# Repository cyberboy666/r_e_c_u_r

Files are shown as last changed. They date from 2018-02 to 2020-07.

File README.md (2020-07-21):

# r_e_c_u_r

 an open diy video sampler
 
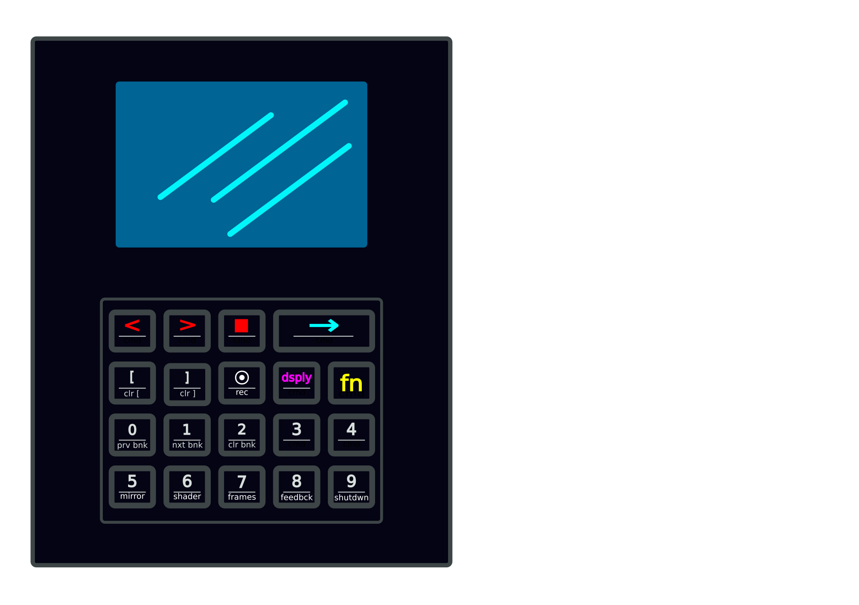
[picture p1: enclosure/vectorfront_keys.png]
vectorfront
 
 
__r_e_c_u_r__ is an embedded python/openframeworks application on _raspberry pi3_ that uses `input` from the _keypad_ to control  `video` while displaying a simple text ui on a _rpi lcd screen_ 

## in-depth video demo

[video-walkthrough](http://www.youtube.com/watch?v=FKKDr7pLpp0)

## features

- seamlessly loop video through rpi's HDMI or composite out
- intuitively _browse_ video files from external and internal disk and map them into __r_e_c_u_r__
- load and trigger video samples from numbered slots in the _sampler_ bank
- dynamically set and clear the start/end points of each sample as it plays
- control and sequence all inputs and more with midi-usb
- many sampler modes for varied playback including: repeat, one-shot, gated, random, fixed-length, random-start and more 
- exhaustive and extendable _settings_ menu  to suit your use

## extensions

as of _V2.0_ the __r_e_c_u_r__ platform has been extended in a number of directions to complement live performance and  _\_recur\__ , the original video playing engine:

- _\_captur\__ : input live video via CSI or USB , for live sampling and processing
- _\_conjur\__ : glsl shader engine, map and trigger shader files and control parameters in real time; generate video or process and mix existing sources
- _\_detour\__ : in-memory frame sampling (up to 500 frames), video scrubbing, playback speed and direction control, finger drumming
- toggling internal feedback + strobe effect 

_NOTE: most of the new V2.0 features are optimised for sd composite video output. Some of these extensions will work over HDMI but they are not fully supported - especially the live video input struggles_

### extension video walkthroughs

- [conjur_walkthrough](https://www.youtube.com/watch?v=ah2HY1fuv8w)
- [captur_walkthrough](https://www.youtube.com/watch?v=e7m_YHEFahs)
- [detour_walkthrough](https://www.youtube.com/watch?v=e9vrzn7c9R8)

## main objectives:

- *Affordable* : reducing the entry cost to performing with video
- *Extendable* : laying the foundations (of a user interface and code style) that can be easily iterated on by the community
- *Simple* : easy to operate (abstracted completely from ‘driving’ a raspi ) , easy to build (no technical computer install-y or circuit-y knowledge required to diy) , easy to develop (human readable code, inviting amateur/first time coders to contribute)

## documentation:

- [operating] - how to use r_e_c_u_r
- [building] - how to diy r_e_c_u_r
- [developing] - how to contribute to r_e_c_u_r

many other things documented on the [wiki]

## status

The nature of this project is to be open-ended and community driven. my r_e_c_u_r already solves the problems i initially built it for. what happens next depends on how it is used and received by you. if you like the idea please let me know / get involved !

## contact, donation and thanks

langolierz@gmail.com

you can find me (and others) at https://scanlines.xyz , an online diy av community space. theres a r_e_c_u_r channel in the chatroom: https://chat.scanlines.xyz/channel/r_e_c_u_r
there is also a facebook user group : https://www.facebook.com/groups/114465402691215/

all feedback is appreciated. if you want to donate to this project you can do so with the above email via paypal : everything i receive will go into improving __r_e_c_u_r__. cheers to Leo Browning for the 3d modelling and vector art and to Ben Caldwell for heaps of help with the code!

[vectorfront]: ./enclosure/vectorfront_keys.png
[video-thumbnail]: https://github.com/langolierz/r_e_c_u_r/wiki/images/video-thumbnail.jpg
[conjur_thumbnail]: https://github.com/langolierz/r_e_c_u_r/wiki/images/conjur_video_thumbnail.jpg
[captur_thumbnail]: https://github.com/langolierz/r_e_c_u_r/wiki/images/captur_video_thumbnail.jpg
[detour_thumbnail]: https://github.com/langolierz/r_e_c_u_r/wiki/images/detour_video_thumbnail.jpg
[operating]: https://github.com/langolierz/r_e_c_u_r/wiki/operate_docs
[building]: https://github.com/langolierz/r_e_c_u_r/wiki/build_docs
[developing]: https://github.com/langolierz/r_e_c_u_r/wiki/develop_docs
[wiki]: https://github.com/langolierz/r_e_c_u_r/wiki

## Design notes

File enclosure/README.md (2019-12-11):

gonna explain a little about the enclosure options here :

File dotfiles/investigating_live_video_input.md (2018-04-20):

# video input

### background

a common feature of audio samplers is the ability to 'live sample' ie have a line in to the device and use this to record a sample directly onto it - usally to be played back again imedantly as part of a performance.

from what i can tell some hardware video samplers also offer this feature. it would be interesting to explore the possiblity of this with recur. some ways to record video into recur include:

- a usb dongle / external capture card
- using a pi camera for live video or rescanning off a screen
- piCapture : a custom video card built for pi to use the pi cam protical

the first option seems fiddly and difficult / a compromise. i might be interested in trying to capture with a Blackmagic Intensity Shuttle if i get one some day...

options 2 and 3 both seem plausable, and hopefully will be interchangable once things are working (piCapture claims to act exactly like a piCam so should painless). also this allows both a cheap/hacky solution (rescanning through $2 camera) or a more professional option ($130 addation) and i can start experimenting now with a cheep cam before investing in the expensive piCapture.

i know piCam and piCapture recommend using python and there is libraries for this

### things to find out

i want to know how plausable it would be to add live sampling to my current recur stack (gpio lcd screen, omxplayer video backend).

some things i want know are:

- how to set up the piCam on raspberry pi
- how to record the input from the piCam onto the pi
- will these files play back in omx/recur
- can you preview the stream on the hdmi/composite output ?
- can you preview the stream on the lcd display ? 
- can this preview be adjusted / resized etc ?
- can you adjust params of camera ? in real time ? framerate , brightness , contrast , zoom etc ? 
- how does rescanning look ?
- how could i control piCaptures additional params ?
- is there any reason to think piCapture wouldnt be interchangable with a working piCam feature ?

### research

[cheep cameras] for raspi can be bought from china with 5 mega pixals / recording 1080p video for around $5usd. i have borrowed a camera ~~which i think is a night-vision version~~ to experiment with , although should order one of these myself.

i started by reading the [picamera] python package docs. this seemed to have lots of options regarding recording video , including starting and stopping both previews and video recordings , the ability to set the resolution , framerate , shutter speed of the camera , switching preview to full screen or setting the size and position of it. 

also a bunch of parameters that might be of interest including brightness , colour effect , contrast , flips and rotations , preview alpha , saturation , sharpness. these apear to be controllable in real time while previewing or recording.

it seems like the output from the camera is raw (without frame per second meta data) h264 and to play the video back at correct speed will need a program to wrap it in an mp4 container :
```
$ sudo apt-get install gpac
...
$ MP4Box -add input.h264 output.mp4
```

the [faq] also addresses the 'can i preview to the lcd screen' question : looks like no - atleast not without copying the exact framebuffer , similar to my experiments displaying omx on the lcd screen. (this still might be possible in the world of openCv but off the table for now! - or maybe not even then - this [adafruit] tutorial talks about the limitations of displaying on a tft screen - "accelerated software will never appear on the PiTFT (it is unaccelerated framebuffer only)" ) 

### an unrelated aside : 

the [adafruit tft display] mentioned above also uses the gpios to connect to the pi - in particular it uses 5 spi pins and two standard pin outs. by cross refferencing the [raspi gpio] docs it does not use either of the rx serial pin , which would be needed if i were to receive midi directly (rather than through usb), it also leaves plenty of pins for receiving cv from a [mcp3008] through software spi for example. it is likely that my gpio lcd screen comunicates with the pi in a similar way and that i could figure out a way to connect these extentions if desired.

### research continued : piCapture

[picapture] is a video capture card designed for the raspberry pi to emulate the piCamera and take advantange of the pi's hardware accelaration. it comes as a 'hat' that also uses ic2 (or serial)
to comunicate. there is a python package to access these addational options. 

these come in two types :

- standard def - composite and s-video in , $139usd
- hi def - hdmi and component in $159usd

im not sure which one i would like to try, but they sound cool ! would need to check the pins dont clash with the display but i think these should work together nicely !

### getting started with piCamera

following the picamera docs , i will/have :

- plugged in the camera
- turned on camera in the config
- tried take an image
- installed package with `sudo apt-get install python3-picamera`
- run `sudo apt-get update` and  `sudo apt-get upgrade` (for firmware)
- trying some simple python commands with camera
- write some experimental recur code

first hitch : i enabled the camera in the raspi-config , but it seems like the switching screens driver overrides this , ~~so will have to update this too !~~ fixed this by adding a line to the config.txt

besides that the preview / different parameters and effects work as expected. next step is to try recording something , converting it to mp4 and playing back on omxplayer.

i have installed `sudo apt-get install gpac` and am using `subprocess.Popen` to run the `MP4Box` command from inside python. this way i can poll back into it and map the video only when its finished converting to stop blocking in the meantime. i also updated the display to show when the camera is previewing and recording. this all worked smoother than i expected.

i also made a (suprizingly small) change to the browser to show the pi's videos folder next to the external devices. this will be useful for using the recordings saved and for copying files onto recurs disk. (the copying feature has been depriotised since it can be done manually with mouse/keyboard and could be risky / might want a confermation window ...)

another thing still to think about is how to protect from overfilling the sd card / external storage. 
- i have done this by checking before starting to record and every 10 seconds during recording if the disk space is under 10mb in which case it warns and stops the recording.

also displaying info when camera is not attached and catching other types of errors... 
- this will be handled by  bool enabling the capture. if it can not detect the camera it will not allow this to be enabled.

[picamera]: http://picamera.readthedocs.io/en/release-1.0/api.html
[faq]: https://picamera.readthedocs.io/en/release-1.13/faq.html
[adafruit]: https://learn.adafruit.com/adafruit-pitft-3-dot-5-touch-screen-for-raspberry-pi/easy-install-2
[adafruit tft display]: https://www.adafruit.com/product/2441
[raspi gpio]: https://www.raspberrypi.org/documentation/usage/gpio/
[mcp3008]: https://learn.adafruit.com/raspberry-pi-analog-to-digital-converters/mcp3008
[cheep cameras]: https://www.aliexpress.com/item/5MP-Camera-Module-Flex-Cable-Webcam-Video-1080-720p-For-Raspberry-Pi-2-3-Model-B/32860830711.html
[picapture]: https://lintestsystems.com/products/picapture-sd1

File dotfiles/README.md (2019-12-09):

# documenting the exact steps to creating the r_e_c_u_r raspbian image

## initial set up ; flashing fresh sd, keyboard , wifi , updates etcs

- downloaded the latest (~~2017-11-29~~ ~~2018-04-18~~ [2019-07-10]) raspbian-raspbian-lite image from offical site.

- flashed it to my sd using etcher

- set up auto console login and changed keyboard layout using `sudo raspi-config`

- following the beginning of [this](https://gist.github.com/kmpm/8e535a12a45a32f6d36cf26c7c6cef51) guide,
set up wifi and run all updates: 

`sudo nano /etc/wpa_supplicant/wpa_supplicant.conf` Add the bottom of the file
```
network={
  ssid="YOUR_SSID"
  psk="YOUR_PASSWORD"
}
```

then `sudo apt update` and `sudo apt upgrade` , sudo reboot

- i trieds to get this working without needing pixel installed (using openbox and a few other bits but the drivers for my screens didnt work like this - decided its not worth shaving that yak rn. will proceed with a stripped pixel as described above:
 
## download/install pixel + all dependencies for r_e_c_u_r : 
 ```
 sudo apt-get install -y raspberrypi-ui-mods git python3-tk omxplayer libdbus-glib-1-dev python3-pip unclutter python3-picamera gpac 
 
 pip3 install dbus-python omxplayer-wrapper  mido python-rtmidi
 ```

- now can set up auto desktop login using `sudo raspi-config`

## download the code in this repo:

- pull down recur code into home dir ~ : `git clone https://github.com/langolierz/r_e_c_u_r.git`

## quiet x and run my launcher script on boot:

- used ~~sudo nano ~/.config/lxsession/LXDE-pi/autostart~~ `sudo nano/etc/xdg/lxsession/LXDE-pi/autostart` to add these lines : 
```
@unclutter -display :0 -idle 0 -root -noevents
@xset s off
@xset s noblank
@xset -dpms
@bash /home/pi/r_e_c_u_r/dotfiles/launcher.sh
```

and remove the line `@point-rpi` 

these are suppose to stop screensaver / hide cursor / remove on screen power warnings etc

- i then went into pi item -> Preferences and set a black background , small task bar , no screensaver  and went into the file explorer -> Edit -> Preferences -> Volume Managment -> unchecked 'show available options for removable media ...' and made taskbar auto hide...

- created internal storage folder in ~/Videos 

- set a custom splash screen by replacing splash.png an image at:
`sudo cp ~/r_e_c_u_r/documentation/splash.png /usr/share/plymouth/themes/pix/splash.png`
 
## for piCaptureSd1

need to install : `sudo apt-get install python3-smbus` and `sudo pip3 install pivideo`

## lcd display drivers

these are the drivers for the waveshare displays that work on the cheep lcd i ordered online ( [LCD-show-170703] ).~~

`git clone https://github.com/waveshare/LCD-show`

my screen only needs the LCD35-show-180 and LCD-hdmi scripts. after running both of these scripts the drivers can be deleted since the recur code then handles the switching. (or keep em if you wanna flip the screen or try calibrating the touch screen)

## installing raspi2fb

i decided to use AndrewFromMelbourne's [raspi2fb] to get a approx of output on the lcd screen. following their readme i installed :

`sudo apt-get install cmake libbsd-dev`

 pulled down the code from home dir  `git clone https://github.com/AndrewFromMelbourne/raspi2fb.git` 
 
 moved into the folder then ran the following commands : 
 ```
 mkdir build
cd build
cmake ..
make
sudo make install
sudo cp ../raspi2fb@.service /etc/systemd/system/
sudo systemctl daemon-reload
sudo systemctl enable raspi2fb@1.service
```
a line to Popen inside the python code toggles this on and off from here.

## lines added to config.txt

the fastest way is to copy the config.txt i included in the repo:

`sudo cp ~/r_e_c_u_r/dotfiles/config.txt /boot/config.txt`

be careful though - messing with the config.txt is the easiest way to brick the image from my experience ... 

or do these :

- commenting out hdmi_force to allow composite output: `#hdmi_force_hotplug=1`

- add these lines to the config:
```
## gives more memory to the gpu for playing 1080 videos (might need to adjust this when using older pis with less memory)
gpu_mem_256=120
gpu_mem_512=200
gpu_mem_1024=448
gpu_mem=600
## enables the raspi camera
start_x=1
## fixes bug with playback freezing
audio_pwm_mode=0

## persisting composite settings
sdtv_mode=00
sdtv_aspect=1

## switch for enabling lcd screen (the next line is being used even if its commented out)
##no_waveshare_overlay
```

## changes to the cmdline.txt

add to end of cmdline.txt `sudo nano /boot/cmdline.txt` : 
`quiet splash logo.nologo plymouth.ignore-serial-consoles` for quiet boot with splash screen 

## installing openframeworks and setting up conjur app

`wget "https://openframeworks.cc/versions/v0.10.1/of_v0.10.1_linuxarmv6l_release.tar.gz"`

- `mkdir openFrameworks` and `tar vxfz of_v0.10.1_linuxarmv6l_release.tar.gz -C openFrameworks --strip-components 1`
- `cd openFrameworks/scripts/linux/debian/` &  `sudo ./install_dependencies.sh`
- `make Release -C ~/openFrameworks/libs/openFrameworksCompiled/project`
- `cd ~/openFrameworks/apps/myApps/` and `git clone https://github.com/langolierz/c_o_n_j_u_r`
- `cd ~/openFrameworks/addons/` and `git clone https://github.com/langolierz/ofxOMXCamera.git` (will swap this out for main once/if my edits work and get in)
- `git clone https://github.com/langolierz/ofxVideoArtTools`
- `git clone https://github.com/timscaffidi/ofxVideoRecorder` and its depend : `sudo apt-get install ffmeg` 
- `git clone https://github.com/jvcleave/ofxOMXPlayer` and install depends : `cd ofxOMXPlayer; ./install_depends.sh` and checkout last stable version `git checkout c826828`
- `git clone https://github.com/kashimAstro/ofxGPIO`
- `git clone https://github.com/danomatika/ofxMidi`
- `git clone https://github.com/jeffcrouse/ofxJSON`
- (install dependances for of ??)
- `make ~/openFrameworks/apps/myApps/c_o_n_j_u_r`

## installing packages and apps

- `sudo pip3 install Adafruit_GPIO Adafruit_MCP3008 RPi.GPIO pivideo python-osc` (tried to install threading but didnt work...)
 - (note atleast pivideo needs to be installed with sudo.), also needs `sudo pip3 install serial``
- pip3 install gitpython
- `sudo apt-get install glslviewer`

### installing ttymidi :
- `wget http://www.varal.org/ttymidi/ttymidi.tar.gz` and `tar -zxvf ttymidi.tar.gz`
- `cd ttymidi` and `sudo nano Makefile` then add `-pthread` after -lasound ... 
- then `sudo make` then `sudo make install`

## setup:

need to delete the old settings : `rm json_objects/settings.json` ~~and create a `Shaders` folder, also need to put default.vert shader in there for any shaders to work !~~

i think will need to turn on the i2c and serial interfacing... (and maybe that serial switvhing thing .. oh and the clocking for midi serial ...  )

NOTE: need to disable console logging and enable seial through the raspi-config !

these amount to the following in the config:
```
dtparam=i2c_arm=on
dtparam=spi=on
enable_uart=1
```
plus this for serial midi : 
```
#setup midi over serial
dtoverlay=pi3-miniuart-bt
dtoverlay=midi-uart0
```

# wjhat follows is info, not instructions for setup:

## key mapping and the launcher script:

because the keypad i bought had some special keys (eg numlock) that interact with the others in ways i didnt want , i decided to remap the keys on it to letters a-s in order. to do this i used `xmodmap`:

you can find the current keymappings using `xmodmap -pke` and for the specifically numpad related keymappings use:

    xmodmap -pke | grep KP > defaultKeymap
    xmodmap -pke | grep Nu >> defaultKeymap

which prints only the default numpad keys to a file for reference later.
keys can be manually remapped using `xmodmap -e "keycode 82=a"` for testing.

In order to have the custom keymap work on startup we have added the line `xmodmap ~/r_e_c_u_r/dotfiles/.remap` to the launcher script where the file `.remap` has a list of the keycodes that you want to include.

## exporting image

first remove my wifi password ! (and git profile if present)

`sudo nano /etc/wpa_supplicant/wpa_supplicant.conf`
`git config --global user.email ""`
`git config --global user.name ""`

i exported the image using unix command `dd` from the raspberry pi i wanted an image of.

i had some success using [pishrink], following the instructions on readme exactly , i managed to reduce a 3.8gb image down to 2.9gb and then zipped down to 1.15gb, (this would be more useful with larger cards though).

- the flow is using dd to copy the image from the pi to an external drive `sudo dd bs=4M if=/dev/mmcblk0 of=/media/pi/FLASH DRIVE/recur.img`

- then use pishrink to reduce this image `sudo pishrink.sh recur.img` it fails the first time but works straight after - not sure why !

i had a `Unexpected Inconsistency` problem with my image which [this link] helped solve.

- then gzip to zip this : `sudo gzip recur.img`

[2019-07-10]: https://www.raspberrypi.org/downloads/
[pishrink]: https://github.com/Drewsif/PiShrink
[LCD-show-170703]: www.waveshare.com/w/uplosd/0/00/LCD-show-170703.tar.gz
[raspi2fb]: https://github.com/AndrewFromMelbourne/raspi2fb
[this link]: https://chrisdown.name/2011/06/01/fsck-partitions-inside-an-image.html

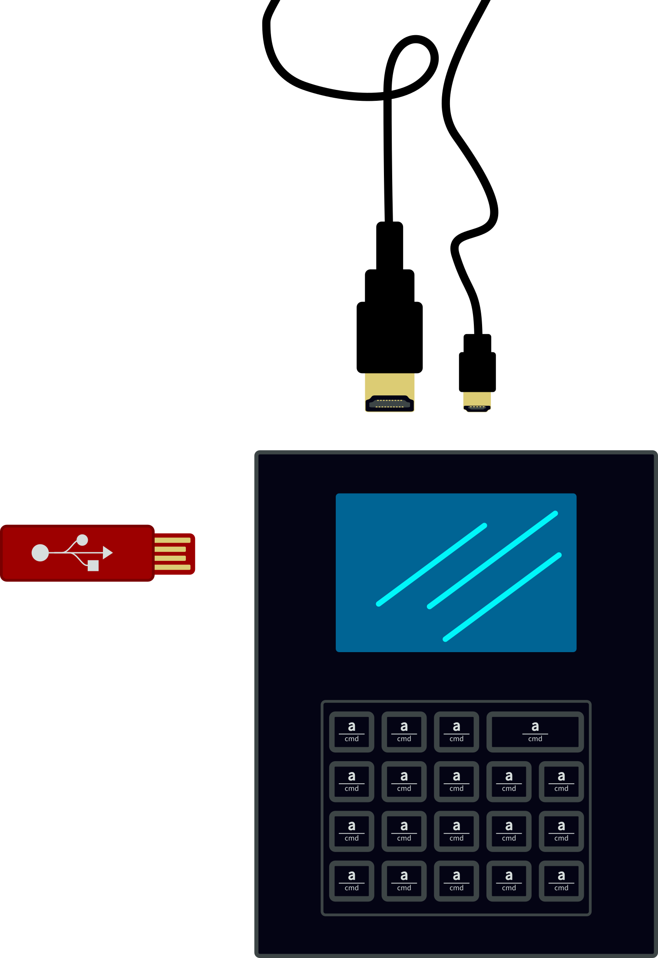
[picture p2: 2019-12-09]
enclosure/vectorfront.png

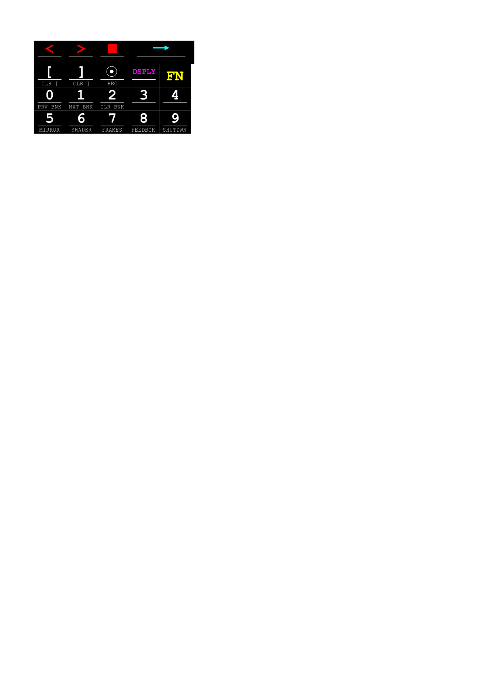
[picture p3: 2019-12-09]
enclosure/keystickers.png

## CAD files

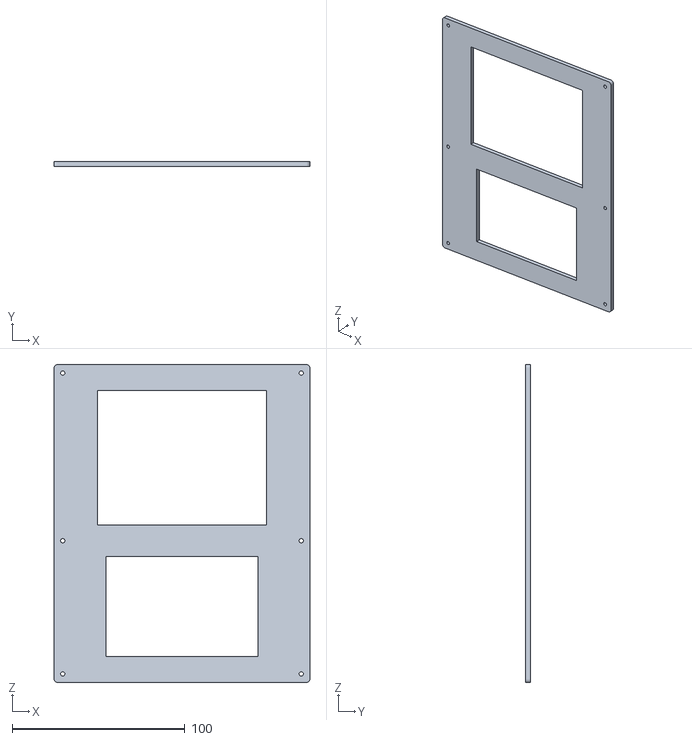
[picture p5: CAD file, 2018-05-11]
enclosure/topplate.stl
148.0 x 3.00 x 184.0

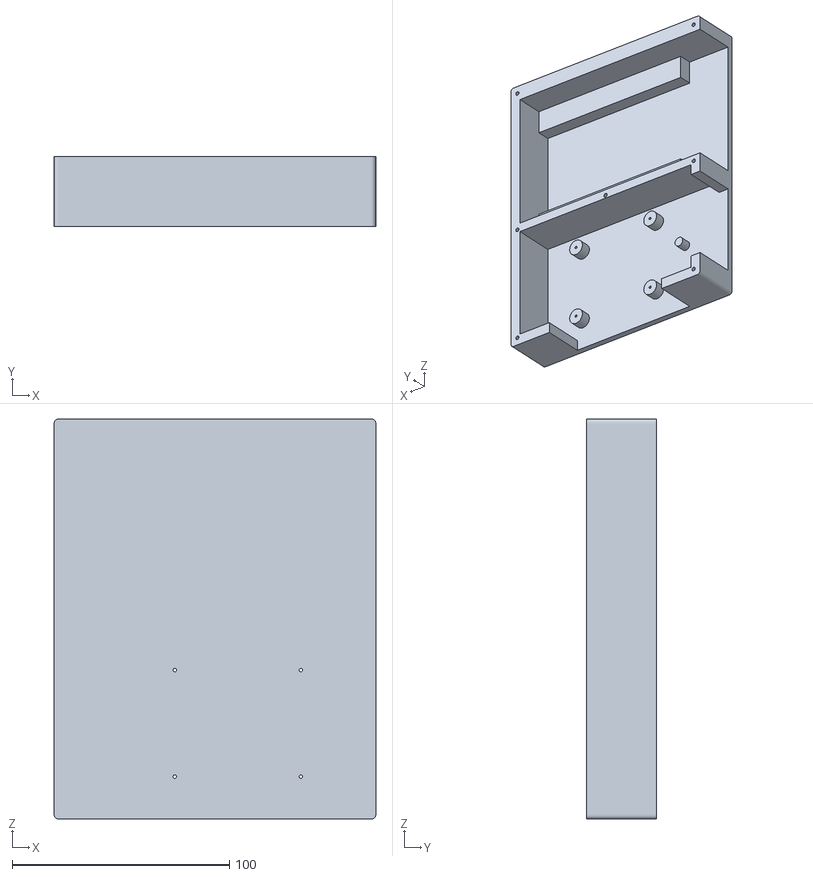
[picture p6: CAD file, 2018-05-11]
enclosure/baseplate.stl
148.0 x 32.0 x 184.0

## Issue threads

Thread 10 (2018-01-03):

some keys on the num pad are not usable on device

langolierz, 2018-01-03:
the numlock key and the 000 key have a specific operation that makes it difficult to map within the program. a custom keyboard layout will need to be created on machine to strip these functions and make it easier.

leobrowning92, 2018-01-12:
key remappings were achieved using the program `xmodmap`, and the most helpful post
you can find the current keymappings using `xmodmap -pke` and for the specifically numpad related keymappings use:

    xmodmap -pke | grep KP > defaultKeymap
    xmodmap -pke | grep Nu >> defaultKeymap

which prints only the default numpad keys to a file for reference later.
keys can be manually remapped using `xmodmap -e "keycode 82=a" for testing.

In order to have the custom keymap work on startup we have added the line `xmodmap ~/.remap`

where the file `.remap` has a list of the keycodes that you want to include.

TODO add the `.remap` file to the project directory once complete

leobrowning92, 2018-01-14:
the info aboce was added to the dotfiles readme. the .remap file still needs to be added to the dotfiles folder.

after that is done, I think that this issue can be closed, as the ongoing problem with the 000 key is being handled in issue #29

langolierz, 2018-01-14:
sounds good - i will do this and close issue

sym3tri, 2021-03-13:
Hi. I'm a newb here and looking for help debugging my janky keypad that's not working. I understand the above description, but I can't find any docs on where to actually place the remap file. I guess I would have to rebuild everything from source just to get the keys to remap... is that how it works?

Closed 2018-01-15.

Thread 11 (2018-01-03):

fit/fix the display output to screen size

langolierz, 2018-01-03:
the browser and settings mode only shows 5 lines although the screen can fix more. also the sampler mode has 15 slots in a bank where theres only keys for 10

Closed 2018-01-04.

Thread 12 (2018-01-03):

fix the error handling

langolierz, 2018-01-03:
currently there is some attempt to display info and error messaging on the screen but it needs some work and testing. also should write any 'unexpected' errors to a log file for troubleshooting

Closed 2018-01-06.

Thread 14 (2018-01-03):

rename all usage of 'bank' with 'slot' to avoid confusion

langolierz, 2018-01-03:

Closed 2018-01-06.

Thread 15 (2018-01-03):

fix dev mode

langolierz, 2018-01-03:
when switching dev on mode the pi reboots with display on hdmi out, when off it reboots to display again

langolierz, 2018-01-17:
closing this as is captured within scope of issue #38

Closed 2018-01-17.

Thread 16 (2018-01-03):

export a working image of raspberrian/r_e_c_u_r/for-pi3 and use it to flash new pi

langolierz, 2018-01-03:
also take a fresh raspberian and configure to a working recur by following instructions in dotfile..

langolierz, 2018-04-03:
some progress has been made on this - i have created a file which has the exact steps to run recur from a fresh raspbain image. i just need to write the image on this card , but am waiting on a 4gg card to arrive so my image can fit on smaller cards.

langolierz, 2018-04-30:
this has been done and documented, the current image has some bugs but same process can be applied to a less buggy version

Closed 2018-04-30.

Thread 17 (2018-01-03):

video player can crash when triggering an empty slot

langolierz, 2018-01-03:

Closed 2018-01-06.

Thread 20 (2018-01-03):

create, test and upload v2 of 3d printed panels

langolierz, 2018-01-03:
some things to consider for v2 of panels:

- [x] making the panels thicker
- [x] slightly wider to fix one end of keypad...
- [x] main support holes slightly bigger for screw size
- [x] more support pillars ?
- [x] better screw size? (that doesnt overhang through the top?)
- [x] add small screw holes for raspberry pi
- [ ]spacers between screen and pi
- [x] fitted to the keyboard? a clamp to remove needing to screw in keypad

other vague panel-y things to think about;
how might we design/modify the panels for:

- eurorack format ? breakout connections of pi inputs?
- with extra height/inputs of piCaptureHat ?
- no built in keypad, strictly midi inputs/ a usb a keyboard ?
- other sbc such as orange pi / pi2 etc ?

langolierz, 2018-01-18:
@leobrowning92 i cant assign issues to you unless you are on the project, but you can assign yourself i guess and i can tag you in ones i recommend - lets do/talk about this together but iv tried to write all my thoughts in the description if you wanna start thinking !

langolierz, 2018-04-03:
v2 of the 3d printed enclosure has been designed and printed. i will open another issue for the feedback into v3 , also some comments on the other panel-y thoughts above:

- i have thought about a eurorack format option , however this would be a `deluxe boutique` option that would be the most expensive and time consuming to make. this would use a raspi3 compute with custom wiring to the board and to the keys. i would only make / offer this if i really wanted to make it , or some people really wanted to pay for it
- allowing extra height for piCapture should be trivial to modify from original fusion files , can cross that bridge when it comes ...
- there are plenty of cases for pi's with 3.5 lcd screen that could be used with keypad / keyboard / only midi etc, dont need to provide this
- i am less interested in other sbc for now , focusing on improving the raspi version, however , it would be just moving slightly where the screw holes go

langolierz, 2018-04-05:
i have opened a new issue #56 to track the changes made to this version of the enclosure

Closed 2018-04-05.

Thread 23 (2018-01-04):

seek buttons through errors

ben-caldwell, 2018-01-04:

Closed 2018-01-04.

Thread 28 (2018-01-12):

make a dotfiles directory

leobrowning92, 2018-01-12:
The purpose of a dotfiles directory being to document the necessary configuration changes made to the pi in order to run the project.

The directory can include the actual config files such as

-.remap
-launcher.sh
-.config/xdg/lxsessions.....autostart
-drivers for the screen
-python packages necessary for installation

leobrowning92, 2018-01-14:
done here #30 but the necessary files still need to be added to the folder, and then the readme needs to be updated to detail how and when those files get used.

langolierz, 2018-01-16:
this is pretty much done - can probably be updated/tested while working on issue #16

Closed 2018-01-16.

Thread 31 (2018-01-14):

hide boot text and use custom splash screen ?

langolierz, 2018-01-14:
info on this here https://raspberrypi.stackexchange.com/questions/59310/remove-boot-messages-all-text-in-jessie

langolierz, 2018-01-17:
done some of the work on this but blocked by issue #37 - not a huge priority right now though

langolierz, 2018-01-17:
the above only worked when booting to hdmi - seems like booting to display is different....

langolierz, 2018-04-03:
by adding a few lines to the boot text , (enabling the splash screen) and also including this on the screen drivers it will boot quietly now

Closed 2018-04-03.

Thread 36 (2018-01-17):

duplicate usb folders loaded

langolierz, 2018-01-17:
sometimes the pi loads my usb as 'TIM1' and has a 'TIM' folder stuck in pi/media.

langolierz, 2018-04-03:
this seems to happen when a usb is removed or inserted at after or around boot. with some poking i can probably reproduce it. it can be fixed by deleting the folders mounted. i could make this an action from inside the program if it continues to be a problem...

langolierz, 2018-09-24:
to fix this problem just type `sudo rm -r /media/pi/**name_of_device**`

TubularCorpration, 2020-09-08:
Just a heads up I was experiencing this problem and your solution worked but it also wiped the filesystem of the actual USB stick! I confirmed on a Windows machine, it's empty now.  I have everything backed up so not a big deal but if I didn't it would have been a hassle recovering everything.

langolierz, 2020-09-08:
oh god @TubularCorpration im sorry this happened ! (and lucky you had it backed up!)

i meant to type this with the device _removed_ first. will edit my previous comment to make it clear - thanks for the heads up (you prob saved someone a lot of trouble ! 😅 )

TubularCorpration, 2020-09-08:
Wasn't an issue at all, I just copied everything back on to the USB stick, but I wanted to post about it in here to make sure nobody without backups made the same mistake!

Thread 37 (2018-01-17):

my rasbPi has root account locked - boot in sulogin..

langolierz, 2018-01-17:
basically [this](https://raspberrypi.stackexchange.com/questions/73716/strange-problem-on-startup-cannot-open-access-to-console) exact problem, i have a feeling it has to do with booting with the usbdrive in the pi, not sure tho...

langolierz, 2018-04-03:
i have fixed this by using the newest raspian image stretch , not sure what the problem was but seems to work fine now

Closed 2018-04-03.

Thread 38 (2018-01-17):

modifying the setting tab to toggle values AND evoke actions

langolierz, 2018-01-17:
currently settings is used to toggle things - ie change the screen resolution or switch playback mode etc. going forward we may want to trigger an action (ie quit or restart the program, switch to hdmi out). we also could still access key presses that arnt mapped on keyboard - allowing more flexibility around custom mappings, shortcuts and actions...

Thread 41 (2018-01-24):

creating/accessing different banks

langolierz, 2018-01-24:
at this stage im thinking of keeping this as simple as possible :

- each 'bank' has 10 slots. (a video can be refered to as bank.slot )
- the current display_data.json file will have a list that is appended to
- three new actions : cycle_bank_forward, cycle_bank_back, clear_current_bank
- if your highest bank is not empty then auto create a new empty highest bank. if your second highest bank is clear then auto delete the highest bank.

langolierz, 2018-02-14:
decided to keep features (seperate from issues) in trello

Closed 2018-02-14.

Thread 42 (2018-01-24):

Different play modes including : random, sequence, random start, fixed length etc

langolierz, 2018-01-24:
some ideas for playback modes :

- random : loads a random (non-empty) slot from current bank for next playback
- sequence : allows you to key in a combination of numbers to loop between in current bank
- random start : loads the next video at a random start point
- fixed length : always plays videos for the same amount of time (input from BPM tap or something)

langolierz, 2018-02-14:
decided to keep features (seperate from issues) in trello

Closed 2018-02-14.

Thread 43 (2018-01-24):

recording video input for live sampling

langolierz, 2018-01-24:
an optional extension : c_a_p_t_u_r - for live video sampling.

- uses input from raspberry pi camera (or PiCapture boards)
- a new action : toggle_recording
- when recording is on, display [recxx:xx] between the now and next on video_display panel.
- save the file to flashdrive (or pi?) and auto map to a bank
- have a <CAPTUR> display mode for monitoring video input, and displaying/switching input channels ...

langolierz, 2018-02-14:
decided to keep features (seperate from issues) in trello

Closed 2018-02-14.

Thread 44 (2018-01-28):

changing key mappings on every boot making start up slow

langolierz, 2018-01-28:
currently , we need to press enter on boot. (due to issue #37 )

then after every boot it maps the keys, however this takes up to 4 seconds , which slows loading time. idealy we wont need to enter on boot (or could have that key press do both enter and our key in meantime) so we can keep the custom mapping until we tell it otherwise

langolierz, 2018-04-03:
this turned out to be more trouble than i think it is worth. the boot time is acceptable , and now it doesnt linger on the pixal desktop as before so i am happy with mapping the keys on every boot

Closed 2018-04-03.

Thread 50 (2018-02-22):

check if mapped videos still exist

langolierz, 2018-02-22:
it would be useful if, on startup, the program checked that it could locate each file mapped to a slot. if it couldnt find it, should still display it but grayed out.

langolierz, 2018-04-20:
every time the display is rendered it checks the paths to ensure they are not broken - might be overkill to check so frequently , but short of storing variables , the display needs to know anyway and the ckeck should be quite fast.

also wont let you load a slot that has broken path

Closed 2018-04-20.

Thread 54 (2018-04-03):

compromised video playback on some hdmi displays

langolierz, 2018-04-03:
- i have been using an hdmi-to-vga dongle to test and dev recur on an old vga computer monitor.

with this setup the video playback is exactly as expected, however when i try running recur on a real hdmi the video playback experiences some problems :
- it sometimes freezes the playback a few seconds into playing the video
- when loading the next video it interrupts the current video and gets stuck displaying first frame of next video rather than finishing what it is playing.

i have spend some time trying to figure out why it seems to work for my hdmi-vga dongle, including trying different (lower) screen resolutions but no luck.

this is the biggest and most crippling bug discovered , if this cant be resolved , i couldnt offer hdmi out from this device

langolierz, 2018-04-04:
update : i have been working on this problem today , and think i am a step closer to solving it.

- i discovered an app for raspi called `tvservice` which tells you about the display settings and lets you change them.
- my dongle seems to be recieving dvi , or exactly : `tvservice --explicit="DMT 16 DVI"`
- to see the change you will need to refresh the framebuffer after by `fbset -depth 16; fbset -depth 32; xrefresh -display :0`

hopefully playing around with these will help atleast work around the hdmi issue described

langolierz, 2018-04-04:
the above was a read herring (although could be useful for switching between composite and hdmi without needing to restart...)

i think the problem is a bug with omxplayer around pausing audio sources , i tried disabling hdmi audio and it looks much smoother . phew!

Closed 2018-04-24.

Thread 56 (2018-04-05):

v3 of the enclosure

langolierz, 2018-04-05:

langolierz, 2018-04-05:
- changed the distance between the screen cutout and the rpi screw holes from 3.5mm to 4.5mm in both directions

langolierz, 2018-04-05:
@leobrowning92 , i have made the above changes to the fusion 360 file that you shared with me. could you have a look to see if you can see these changes and if you think they make sense and that i havnt broken or compromised anything ?

langolierz, 2018-04-22:
@leobrowning92 i made another update to the enclosure design to try remove uneeded parts to reduce the print time:

2. edited : changed raised platform for the pi to sit on into four 5mm wide pillars for it to screw into (also might keep the board a bit cooler - i wonder if its enough support for the board though?)

5. edited : changed the keypad platform to two 15mm wide strips (to be doublesided taped to the keypad)

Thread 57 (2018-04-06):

usb not showing when inserted after boot

langolierz, 2018-04-06:
i started up recur , and then plugged in the usb. the files already mapped could be loaded and played fine but the browser mode had not refreshed to reflect this. just need a way to tell the browser list to redraw (if u re-enter the browser screen perhaps ?)

langolierz, 2018-04-30:
havnt seen this issue since - might have been fixed in large refacter of the menus. will reopen if i reproduce it

Closed 2018-04-30.

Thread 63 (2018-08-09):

Add tags to make this easily discoverable on github

leobrowning92, 2018-08-09:
Just realised how important tags are on github when people are searching for repositories.
Would be a good idea to put them in if you are interested in this :)

langolierz, 2018-09-24:
@leobrowning92 from what i can see , tags are directly related to releases , which i havent been using , unless im missing something ? i will create a release for upcoming features soon , so could try adding tags to that ?

leobrowning92, 2018-10-05:
hi, sorry it took a while get back to you. Ooh there is a duplication of terminology here. There are tags for a github repository, which make searching it on github easier. There are also tags which are a feature of git, used to mark certain commits. This issue relates to the first case, tags on github to make things more searchable.

as an aside, github has releases which you mention that can be linked to a certain tag on a commit, or directly to a commit. I have found it very useful to track large code releases in my bigger projects, even just for myself. I have found its a great way to link to output from simulations or generative projects that is a bit coarser then using commits.

langolierz, 2018-10-18:
hah, i cant figure out how to tag the repo (different from a release) and all the info online is referring to the later, can you point me to where i would do this @leobrowning92 ?

langolierz, 2018-11-10:
dun !

Closed 2018-11-10.

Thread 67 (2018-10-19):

close capture object in openframeworks when not using

langolierz, 2018-10-19:
currently when you start a capture in openframeworks using ofRPiCameraGrabber, this resource remains open even when recording/previewing is stopped. this causes increased lag to the sample playback.

it would be better if the capture object was closed between use. however there might be some fiddling with how to open it again etc (will have to play around)

NOTE: although this issue is exclusively related to the c_o_n_j_u_r repo i will put all issues here for simplicity ...

langolierz, 2018-12-19:
i think i have done this by closing the videograbber, and doing a reset when reopening it ...

Closed 2018-12-19.

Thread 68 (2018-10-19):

set sensor mode in ofxRPiCameraGrabber

langolierz, 2018-10-19:
to improve the compatibility of piCaptureSd1 with openframeworks (for live composite processing for example) i have tried to add awbg and sensor-mode options to this of addon. awbg seems to work but i havnt figured out sensor-mode yet.

- when using piCapture through openframeworks there is a glitchy line down the side of the screen - im not sure if setting the sensor mode would fix this but im hoping it will

langolierz, 2018-12-21:
figured it out ! currently using my fork of ofxOMXCamera , will update if it makes it back into the main repo

Closed 2018-12-21.

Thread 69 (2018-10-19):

switch between python/of capture without needing reset

langolierz, 2018-10-19:
currently if you open the capture in say python sometimes it will fail to open in openframeworks , as if the python capture hasnt released the resource needed to open it elsewhere (although i did try to ensure they always close it) , either way some more fiddling with closing cameras etc is needed to make this switch more intuitive

langolierz, 2018-12-19:
just tried this, and although it is true that it did fail sometimes, also without any changes it also works fine (ie couldnt really reproduce the problem) , also a softreset of the program seems to fix it which is a good enough workaround for now... ? will reopen if becomes more problem / can reproduce

Closed 2018-12-19.

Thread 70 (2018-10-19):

openframeworks backend sometimes opens in dev-mode when it shouldnt

langolierz, 2018-10-19:
i have code that switches between full and dev mode (rendering the screen in the corner to mean you can dev on the hdmi out rather than the lcd screen) , and this state should be saved to a xml file that openframeworks reads on boot , however there are still some problems like:

- switching to dev mode when of isnt being used as backend , so it cannot update the file info , perhaps python will have to access this xml file too ?
- others ? not sure...

Closed 2018-12-21.

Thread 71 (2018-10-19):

feedback if loading shader errors

langolierz, 2018-10-19:
currently if a shader fails to compile it will just display a white screen. it would be nice if an info message could let user know that the shader is broken , (or even gray it out like when a video is not there ? although this would require a loop over every shader to check its link ...)

in the openframeworks im using the shaders still report isLoaded = true even though it failed to link,
i found an open pull request that addressed this created two years ago so might need to try merging it in my own fork or something ?

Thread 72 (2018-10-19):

reorganised the setting menu for some clarity ?

langolierz, 2018-10-19:
this isnt really high priory but some of the subsetting menus could be changed, such as :

- replacing midi witht incur , and including analog in switch
- moving of backend switch / capture into its own conjur (or something ?) rather than other,
- dunno if i should use recur instead of sampler - that might be confusing since im still referring to the whole thing as recur (and the sampling subpart...?)
- also i guess thinking about how these settings can help people with specific use cases , for example you might want to turn off browsing video samples since you only live sample , or you might want to turn off the sampler since you only use gen-shaders etc , making it easier to be a single block in a chain of instruments...

Closed 2019-07-16.

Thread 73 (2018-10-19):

create a pcb for simple incur circuit

langolierz, 2018-10-19:
making it easier for people to use continuous inputs from the gpio by creating a pcb that fits the current enclosure and list the parts and details on how to wire it up (with pics etc)

langolierz, 2018-12-18:
this is in progress with first revision on way from fab house. still need to publish a BOM, also got idea for a v2 board that attaches to the pi kinda like a hat would ...

sebiik, 2019-05-06:
My PCB fab house informed me that the gerbers are incomplete, specifically there is "no bottom solder mask layer" present.
I happen to have experience with DIY synth/eurorack/video circuits and could help out with the PCB design. Any interest?

langolierz, 2019-05-07:
@sebiik yess ; oh i forgot i even had gerbers on this repo, since then i have been learning kicad and made some better proto-pcb's for this - just havnt updated here yet.

my first tries had some mistakes in them. the current version is working for analog-ins atleast. i havnt had the chance to test with din-midi yet - as soon as that is confirmed i will upload these improved gerbers.

i am alway interested in help ! email me and we can talk about circuits

langolierz, 2019-08-06:
ths has been updated - schemaic and gerber and a build guide /bom is started

Closed 2019-08-06.

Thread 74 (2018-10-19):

updated versions of the 3d-printed case

langolierz, 2018-10-19:
- for using a piCaptureSd1 hat between lcd screen and pi board , just need to remove the raised stands for pi, increase the height of the whole enclosure a bit, maybe add some vent-like holes for the bottom ?
- for using a custom incur pcb, remove a panel from right of the case next to the pi exactly the same as the removed panel on the left
- both these changes on the same file
- perhaps some better instructions so you know which file to print depending on your use ?

langolierz, 2018-12-18:
my thinking is starting to move away from 3d-printing an enclosure. going to try a lasercut version next (with external keypad control)

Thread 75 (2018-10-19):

create another thorough video walk-through

langolierz, 2018-10-19:
in the same style as the first demo (with 3 separate video feeds and text between explaining functions) , but showing off the new features added

langolierz, 2019-07-16:
i will need a way to capture video output from the raspberry pi - maybe borrow a capture solution ?

the things to show are:
- using shaders (0 and 1 input)
- serial-midi / analog in from circuit board
- new capture stuff (usb)
- new parallel loop mode (controlling two players)
- using shaders to mix (2 input)
- detour demo

Closed 2019-09-25.

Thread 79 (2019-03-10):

using a 3.2' display

hacklab01, 2019-03-10:
Hi, I have a 3.2' pi display.

Editing some stuff in Pi config files of the pre installed image, the display seems to work but the interface is all messed up.

Any way to make it fit into a 3.2' 320 x 240 px display?

Tnx! :)

hacklab01, 2019-03-10:
OK I kind of fixed by changing the font size but some documentation on how ~/r_e_c_u_r/display_centre/display.py is setup might help. :)

timcaldwell-kitchenstories, 2019-03-11:
hey @hacklab01  - cool, i was going to suggest changing the font-size. what size did you set and how does it look ? also what was the config file you changed ? i can add to the faq about 3.2' displays if others want to try it.

and yeah , i know the display code is not that readable and quite 'hard-coded' to that particular screen. i should write a little bit in the develop doc page about it. if you have any suggestions on what would be useful to include lemme know too

ps hacklab01 sounds cool :)

hacklab01, 2019-03-11:
Hi, thanks for the speedy reply.

I changed the font size [here](https://github.com/langolierz/r_e_c_u_r/blob/fa92acca6359fa8a2431509ecdece405816e06a5/display_centre/display.py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)  to 7 but now the ratio is now off. I'll send pics as soon as I reconnect the setup on my desk.

Hehe yeah, tnx, hacklab01 is hackerspace I'm a part of. We have an open call for hacking (or not) related stuff so if anyone is interested in presenting a project / holding a workshop or similar and getting some travel funds / accommodation / pocket money feel free to apply https://hacklab01.org/hackn3t (shameless self promotion).

timcaldwell-kitchenstories, 2019-03-11:
yes pls. wow sounds cool ! i have this and some other upcoming video-hardware related projects  that could be workshops / talks soon. would be nice to visit !

langolierz, 2019-03-11:
whoops commenting on my work account lol. yeah pls send pics of how it looks, i will update the docs and close then close this issue if it looks okay.

and wow ! sounds cool , i have this and some upcoming diy-video projects that could be workshops / talks soon maybe. would be nice to visit !

hacklab01, 2019-03-11:
I mean it's usable I guess (I tried fiddling around with for a bit, didn't get accustomed to the controls yet), just the ratio is really off and there's a lot of screen space empty which could be filled... OK, yeah I'll procrastinate other stuff by sending pics of a raspberry Pi... Why not... =D

Here we go https://imgur.com/a/5Z4O4hE
As you can see I added the same video several times because n00b.

Also it looks like either I'm not getting something or the controls on my numpad are a bit off (it looks like the first row is shifted to the left by one key). Not sure how that happened, I guess I could just remap it by hand, also not sure why that would help (all numpads are the same? Or not?). I'll follow up on that one shortly.

hacklab01, 2019-03-11:
The numpad thing was pretty easy - not all numpads are created equal - mine has the backpspace keys and the minus key switched out. :)

hacklab01, 2019-03-11:
Here's a pic of the numpad https://imgur.com/a/R7MmZbu I don't know the exact model the sticker on the back is scraped off. :)

Yeah i kinda missed the expression, didn't mean the ratio, ment that it's not expanded to screen size. Yeah - If I use a float value for the font size the GUI doesn't load...

I just realized that I missed the pad configuration again haha is it cab or bac or acb noone knows. =D

Another question: Is there a better way to restart the system without restarting the whole pi? Killing python and then running ~/r_e_c_u_r/r_e_c_u_r.py sometimes works and sometimes it just produces a black screen until reboot.

Closed 2019-12-08.

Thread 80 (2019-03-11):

looping buggy?

hacklab01, 2019-03-11:
It's me again - I'm pretty sure this is just me but looping isn't really working for me.

I set in and out on pretty any video I try and get a really jittery erratic experience, a black screen and even lock ups until I clear the deck.

Is there a specific codec omxplayer likes better for looping? My vids are h264 1920x1080.

Could it be the SD card? The card is a new Sandisk card and copy speeds seem fine while testing moving some files around.

Any tips?

hacklab01, 2019-03-11:
I mean, yeah - obviously - the more keyframes you have in your video the prettier the loops are.
If the video doesn't have much keyframes, omxplayer is gonna break while trying to make a loop. :(
Maybe mention something about encoding in the manual? IDK... :)

hacklab01, 2019-03-11:
Just to leave this here if anyone has the same issues as me - it's ideal to have a keyframe on every frame (that creates a larger file but the days of caring about filesize are behind us). The looping then works perfectly, well _almost_. :)

You can just make ffmpeg output every frame as a keyframe with

`ffmpeg -i input.file -q:v 0 -q 1 output.file`

It will select x264 as the codec by itself. -q:v 0 is OK quality for me, if you need better use -crf 17 instead but that makes the file even bigger.

langolierz, 2019-03-12:
hey @hacklab01 ; thanks for the detailed information and suggestion about adding keyframes.

in my experience testing this , i did find some issues similar to what you describe especially for 1080 videos. there is a setting in the menu called 'HDMI_MODE' , which when set to 'CEA 4 HDMI' should drop the output resolution to 720 but handle playing 1080 videos a bit better. and yes i think adding more key frames also helps for seeking to the beginning of the subloop. i will update the faq with this infomation you have included here.

if you felt like sending me one of the files you were using (before adding keyframes) i could test it on my recur to see if we experience the same thing

hacklab01, 2019-03-13:
Hey @langolierz  I'm using RCA output so the HDMI swiitch thing won't help. The video isn't 1080p, I put both files here https://v3d.space/files/ you can download and check. The video is several scenes from  https://archive.org/details/InvasionOfTheBeeGirls . Just pls ping me when you download them so I can kill the directory, because I doubt the movie is really public domain. =D

langolierz, 2019-03-14:
i have downloaded the files so you can bring them down. hmmm.

to reset the program you should be able to stop recur (pressing '.' or maybe fn + 9 ?) ; then start again by running `python3 ~/r_e_c_u_r/r_e_c_u_r.py ` ; having to reclone the repo sounds like a problem with the persisted data - rather than reclone i think you can just delete `json_objects/display_data.json` and/or
`json_objects/next_bankslot_number.json` ;

i assume you are using the v1-image , you might want to try v2beta which can be found here https://github.com/langolierz/r_e_c_u_r/blob/c_o_n_j_u_r/documentation/beta_access_notes_and_limitations_of_v2.md , some bugs might be fixed , then again there might be more. i know that there is a `reset` option in the settings under other atleast in v2beta .

i still think maybe the 1080p files are part of the problem you are having. maybe you could try with a few sd videos and see if the same thing happens ? i will see if i can reproduce these problems soon too

 (ps soz you are experiencing so many bugs ; i hope its still interesting or useful ... )

hacklab01, 2019-03-14:
Hmm, I tried deleting the contents of the json directory cause I figured stuff was there but it didn't help once so I just resorted to cloning.

I'll use the v2 image and report.

The file I sent you isn't 1080p it's an SD file and it still has issues. It doesn't really matter tho, reencoding with more keyframes is simple enough.

I don't mind the bugs at all - I actually had an idea to build a numpad controlled video sampler / player (mine wouldn't have a screen tho haha), so I'm more then happy to help with this as it does exactly what I needed and more.

hacklab01, 2019-03-15:
The beta works much nicer with the openframeworks backend. SD vids loop just fine regardless of keyframes.

I think we can close this and attribute the lockups to omxplayer and HD videos. If you have nothing to add, please close this issue.

The solution is to use sd videos and  the openframeworks backend.

Closed 2019-07-16.

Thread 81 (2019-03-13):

Setting PAL / NTSC doesn't seem to work from menu

hacklab01, 2019-03-13:
Here's me bugging you again. =D

I needed to switch video modes to force it into PAL, and it looks like the switch from the menu does nothing. Needed to go into /boot/config.txt and set it manually (nothing was edited / added to the file after changing the setting).

langolierz, 2019-03-14:
Thanks for the bug reports; i appreciate it. This use to work. I wonder
what has changed. Will take a look into it

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

langolierz, 2019-08-21:
Im not sure if i ever got around to reproducing this altgough other people on the group also reported it . Anyway i think its fixed now. If no one else reports it i will close

Closed 2019-12-08.

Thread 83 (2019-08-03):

some minor recur bugs

langolierz, 2019-08-03:
recur probably will have a few minor bugs i discover but wont fix in a hurry. this is a list of some of them:

- error when bank-slot number saved refers to a bank that is removed (in general persiting this not really need)

langolierz, 2019-08-06:
i just fixed it

Closed 2019-08-06.

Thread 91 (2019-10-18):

Feature Request: NDI Support

teafella, 2019-10-18:
It would be great to be able to feed recur [NDI](https://ndi.tv/about-ndi/)

This would eliminate the need for a capture card when trying to get video out of your computer (or other pis) into recur.

It would also enable you to feed recur further into a VJ setup using Resolume.

Would this be difficult to do?

langolierz, 2019-10-18:
i thought about this too. there is not much info online about ndi on rpi's , i think it is only recently even compatible with ARMs.  if possible it would be through the openframeworks extension ofxNDI , this thread sounds promising - although only sending not receiving , maybe possible in the near future ? https://github.com/leadedge/ofxNDI/issues/4

langolierz, 2019-10-18:
https://forums.newtek.com/showthread.php/151197-NDI-for-arm-devices

teafella, 2019-10-18:
I have a C++ class for sending NDI if you are interested, I'm not sure how easy it is to include in the python codebase though. NDI has a specific shared binary for rpi at /lib/ndi/arm-rpi3-linux-gnueabihf/ on the linux lib

Idk how this works with ofx since ive never used it. From what I understand its C++ based so it should be possible.

I haven't spent time properly testing the receiving code yet but it seems to be working based on the test code in the library.

langolierz, 2019-10-21:
cool ! that sounds promising , the r_e_c_u_r backend is based in openframeworks, which yeah is just libraries around C++ , so it should be possible. i will have to look into this and have a play around. im not much of a C++ dev though so lets see. if you get receiving code working in C++ i would be keen to have alook

magdesign, 2019-10-24:
Sienna said they can do it:
https://twitter.com/NDI_Cloud/status/1145754510343778314?s=19
but nothing to find. Asked the support and they said "no known release date...."

teafella, 2019-11-21:
I tried implementing a receive on the PI and I am only able to receive audio at the moment, which leads me to believe the SDK doesn't support video, I am contacting ndi via email to see whats up since a new version of NDI was just released.

From what I gather from the forums, the issue is lack of ndi codec for arm based processors.

Re Sienna:
Their iPad app (ipad is arm based) also seems to receive NDI, though its very laggy and freezes after like 5 min. I'm not sure how they where able to hack this together...

teafella, 2019-11-21:
Reply from NDI support:
"At the current time we do not have an optimized version of the ARM decoder. This is something we would like vey much to do but it takes quite a bit of time and it is not something that we currently have our own need for and so we need to always find a way to fit this work between other tasks. If there are any parties that want to work with us on an optimized version of the codec we'd be happy to help them contribute to this, it would typically require knowledge of ARM assembly.

Andrew"

Anyone good at ARM assembly over here? lol

magdesign, 2019-11-21:
I think this guys would be able to write the code:
https://github.com/z37soft/INetSyphon_RaspberryPi_SDK
http://www.techlife.sg/

langolierz, 2019-11-22:
Thanks for the update ! Def would be keen to intergrate this once it is
supported; a bit out of my depth to help with that but will keep an eye on
the progress :) , please let me know if you hear more !

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

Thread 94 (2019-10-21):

new display mode : shader_launcher

langolierz, 2019-10-21:
functionally the same as the SAMPLER mode, but for shaders, ie you can map a shader_file to a bank/slot from the shader_browser (maybe by pressing FN + SQUARE), and then launch corresponding shaders with the num keys, same keys for next page etc ...

... would also be nice if these shaders were in a different 'node' to the Fn + 6 shaders so there was more options for chaining them etc ...

ParticlesIntoWaves, 2019-10-21:
I almost see this as being added to the sampler playlist so I can switch between video clips and shaders seamlessly. And being able to call them up the same as video clips would be nice.

In addition to this it would be nice to be able to have a playlist of FX shaders that can also easily be switched. You could process a video feed (or clip) with a curated bunch of alternating FX either with manual key switching, MIDI, or even a fixed length!

Closed 2019-12-08.

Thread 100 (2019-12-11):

MIDI Enhancement: CC parameter “catch up”

ParticlesIntoWaves, 2019-12-11:
As of now, recur will will instantly change a shader parameter to whatever value it receives from MIDI CC. This often results in a jumpy image when the shader has been switched, or edited using the keypad.

A solution for this would be to include catch up and relative modes for MIDI inputs.

In catch up mode, the shader parameter does not update until the MIDI CC input crosses its current value. For instance, imagine I changed shaders and X0 is on .5 but my MIDI knob is currently at a CC value of 0. With catch up activated, the shader parameter would not begin updating until the CC value crosses 63, giving the knob parity with the parameter.

Relative mode is similar but more immediate. A parameter would begin updating immediately when an offset CC is received, but only at a relative value to the MIDI CC. So if X0 is .5 and MIDI knob is 0, X0 will immediately begin changing as I increase the CC value, but starting at .5 instead of 0. When CC reaches 63, X0 would be now at 1, but full range of the knob isn’t restored until the CC reaches 127 and catches up to the parameter.

doctea, 2019-12-19:
Do you have any examples of open source projects that do this so that I can get some inspiration for how to implement this?  I really need it for my customisations too now..

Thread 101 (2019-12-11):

MIDI Enhancement: assignable macro CC mapping in recur

ParticlesIntoWaves, 2019-12-11:
Messing with my Kaoss Pad, and realizing how amazing it would be to control multiple shader parameters with one CC. A menu option to assign this in recur would be phenomenal. Reserve two MIDI CCs for "X" and "Y" (to keep with the Kaoss theme) and allow up to three shader parameters (lay0 x0 to lay2 x3, and what the hell add strobe while you're at it) to be assigned to each one in the menus.

NOW you can pull up on an Entrance :)

langolierz, 2019-12-11:
i dont quite get what you mean in this one - a kaoss pad is just two seperate cc channels for x and y no ? you want both channels to map to the same parameter or ?

ParticlesIntoWaves, 2019-12-11:
I was only referencing the Kaoss Pad as a use case example. Pitch bend and mod wheel work just the same for the sake of illustration.

The idea is to have macro control over multiple shader parameters simultaneously from a single MIDI CC. For example “Macro 1“ would receive only on CC13, but would alter 3 destinations in the shader modifiers, from lay0 X0 to lay2 X3. I think, because different combinations of shaders would require different combinations of parameters for practical macros, it makes the most sense for this to be available in the menus so it can be altered on the fly.

Having just one of those freely assignable shader macros would be pretty bonkers, having two would be stellar!

doctea, 2019-12-12:
The very basic use case here can already be done by editing the midi mapping file I think?  Possibly need some new actions adding too though.

This could be partly implemented with the 'custom plugin script' idea, if the custom scripts will be able to intercept MIDI messages and reroute them...

However, what I think would also be necessary for this to work well (if I've understood it right) is to have a way to adjust the value mapping from the CC -> target parameter using a user-entered formula.  So for example,

"Target A value = input" for straight mapping,
"Target B value = 1 - input" for inverse mapping,
"Target C value = 0.5 + input/2" to set the value range as 50-100%

(Similar to the way that you can map controller values with formulas in FL Studio)

I'm currently experimenting with some enhancements to the actions & MIDI mapping to support 'odd' controllers, if I'm successful I think I'll have a lot of these MIDI requests covered :)

ParticlesIntoWaves, 2019-12-12:
Yes, I figure one could effectively accomplish it by editing the map file to make one CC edit three parameters, but if the shader configuration changes then the macro may not be suitable anymore. Which is why I advocated for an option to map this inside the menus :)

The suggestion for how to interpret the input is great. A simple way to implement this would be a positive and negative offset to each parameter slot in the macro. That would allow bipolar manipulation with fine Or wide control for specific parts of it.

ParticlesIntoWaves, 2019-12-12:
You know... now I have to advocate for THREE macros because I just had another totally sick idea.

Again, use case scenario, but the KP3 can send three CCs from the touch pad, one each or X and Y, and a third for touch on/off. If I had three macros I could use the MIDI touch data to turn my shaders on or off when using the pad! Damn that would be so cool and would definitely blow away an entrancer ;)

Damn it, you’re going to make me get into coding.

doctea, 2019-12-13:
The other requirement you're asking for here would be per-shader parameter mappings, I think?  or just a way to switch between different sets of mappings quickly would achieve it?

ParticlesIntoWaves, 2019-12-14:
I want to be able to program the individual assignments in the menu on the fly. I‘m imagining a macro menu tree in the settings that expands into three slots. Each slot can load any shader layer’s x#, and has modes for interpretation (positive, negative, offset, relative, catch up, etc).

doctea, 2019-12-14:
So sort of like a meta-preset mode?

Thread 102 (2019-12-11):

MIDI Enhancement: New default mappings

ParticlesIntoWaves, 2019-12-11:
Because I'm entitled... I think it would be a good idea to give any toggles and macros their own MIDI CC/note in the json map. I realize I could edit the file myself, but to me it's logical that these simply be included by default because it removes a very tedious and confusing step from the process for users and immediately opens up recur for deep mappings with external controllers.

Any function that requires a key macro, and many toggles in the menus could be added, such as:

X3 as speed on/off
Video bank select
Shader bank select
Feedback on/off
Shader lay0,1,2 on/off
etc. etc.

I'm sure this isn't high priority, however I do believe it would make recur more accessible from the get-go, and then no one ever has to mess with the json files to achieve this extra level of control.

langolierz, 2019-12-11:
im thinking , maybe a setting where you can toggle different mapping files ? then you or anyone else can make there own custom mappings (with all the flattening / macros etc they want) and everyone can share and choose whichever suits their controller / setup ?

ParticlesIntoWaves, 2019-12-11:
My thought was that the default map installed with recur should _also_ include a lot of the common FN macros or menu toggles individually mapped because it would effectively democratize the MIDI mapping process and make deep integration with MIDI devices relatively painless for anyone. If I need to help create this that’s great, but I’ll need lots of help :p

doctea, 2019-12-12:
There are already quite a lot of functions mapped to note_on MIDI messages in the default MIDI mapping, but I'm working on some enhancements in this area as not all features are currently exposed in a way that makes sense to MIDI map.

I'm not familiar enough either with standard MIDI CC controls or r_e_c_u_r to know precisely what the best mapping of CC->function would be, but providing some default templates for different functions seems a good idea, just needs the ability to toggle mapping files and someone to write mapping files for different workflows/controllers!

@ParticlesIntoWaves : if you have any ideas on what the default mappings should be then please share :)

Using json as the file format for configs is also a little bit awkward as its not possible to add comments, maybe should think about switching to a different file format so that the config files aren't quite so daunting to edit by hand for those wanting to customise things?

ParticlesIntoWaves, 2019-12-12:
For any function that is a toggle, macro or otherwise activated with a MIDI note trigger, I think the MIDI note number assigned would be ultimately irrelevant, however I suppose the most logical arrangement is to be organized around middle C.

For any continuous controls, it makes sense to start at CC# 74, which on most synthesizers is the filter cutoff frequency. It may sound arbitrary but it’s one CC# that any MIDI user is sure to know. I would recommend avoiding the first 25 or so CC#s because things like program changes and after touch are sent here and that can confuse things. My r_e_c_u_r currently changes settings when I switch programs on my KP3 because r_e_c_u_r is accepting CC0 to edit shader layer 1.

ParticlesIntoWaves, 2019-12-12:
At any rate, a flattened MIDI map included in the default json would make this all painfully easy, for me at least.

langolierz, 2019-12-13:
do you have a suggestion for another file format ? i guess you can
comment in yaml ? but yah. i chose json coz i thought it would be more
human readable... but i get that its knida confusing, obvs a ui around this
would make it easier, actually have some ideas around building mappings
more easily ...

On Thu, Dec 12, 2019 at 7:38 PM ParticlesIntoWaves <notifications@github.com>
wrote:

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

doctea, 2019-12-14:
I've just pushed code to my midi feedback branch that automatically loads a custom midi mapping file if one exists based on the device name, and activates the experimental feedback mode if an APC Key 25 is detected.

Expanding this, if we collect midi mapping files from people with different controllers then this should make it easy to have 'plug n play' 'out of the box' support for different controllers and workflows.  although I guess it would still be good to be able to override that in the menus.

And if the file format is going to change then we should do that before getting people to send their configurations I guess...

I'm afraid I don't have much of a suggestion on file formats.  json would be pretty great tbh if only it supported comments!

what about using python itself for the config files?  would the basic syntax for defining variables and trees of lists be too confusing?  it would certainly make it easier to map ranges of notes/CCs to banks/slots without a lot of error-prone typing and duplication...

ParticlesIntoWaves, 2019-12-15:
Plug and play would be nice but it would be dependent on the controller’s ability to load matching profiles, since controllers can be programmed a number of different ways. If all useful r_e_c_u_r functions were individually MIDI mapped in the default json, I could whip together a custom profile on any of my controllers, tailored to r_e_c_u_r, in a couple minutes, which is how I’d use it any other context. A synth or MIDI device usually has uneditable CC receivers. A MIDI controller is mapped to send on those channels.

doctea, 2019-12-15:
> Plug and play would be nice but it would be dependent on the controller’s ability to load matching profiles, since controllers can be programmed a number of different ways.

That's what the code in my experimental branch does, loads a different config file based on the detected name of the MIDI device.

>If all useful r_e_c_u_r functions were individually MIDI mapped in the default json, I could whip together a custom profile on any of my controllers, tailored to r_e_c_u_r, in a couple minutes, which is how I’d use it any other context.

Which functions are currently missing from the default config that are preventing you from doing this?

Would a list of the commands available for mapping help?  There are likely some missing and maybe you can point out some of the blanks that need implementing.

>A synth or MIDI device usually has uneditable CC receivers. A MIDI controller is mapped to send on those channels.

MIDI controllers are often uneditable and non-standard too -- for example I've been using both an Axiom Air32 Mini and an Akai APC Key 25 and they each send out different ranges of CC values (CC#0 vs CC#48 for example), notes on different channels etc so it makes sense to have configs for different controllers.  I know the Akai APC Mk2 has its own quirky CC/note mappings too.

If you could write a mapping file that covers all the defaults you'd expect then I bet that could be integrated, however its difficult to know what functions you'd expect to find on which notes/CCs?

langolierz, 2020-03-12:
will create a new issue for greater midi controller / mapping handling in general , for now i have added some flattening to the default midi mapping as originally suggested

Closed 2020-03-12.

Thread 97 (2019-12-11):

MIDI Enhancement: input smoothing/slew

ParticlesIntoWaves, 2019-12-11:
I would like to one day see recur able to smooth out MIDI input. Right now, shader edits made with a MIDI controller are a bit jumpy since it’s a stepped motion. Adjustable slew rate would make that all a lot more fluid.

On a side note, I think it would also be a good idea if the values were 1:1 with MIDI, so 0-127 instead of 0-99

langolierz, 2019-12-11:
i get what you mean, also though, its more 'stepped' than 127 steps because trying to save on resources :
https://github.com/langolierz/r_e_c_u_r/blob/master/user_input/midi_input.py#L70

 i think if this step size was 1 or 0 it would look a lot smoother. you can experiment with changing this value on your machine if you like - also ofcourse pi4 might also help here ;)

ParticlesIntoWaves, 2019-12-11:
So what you’re saying is you can’t smooth it anymore because the input values of the shaders are low resolution? Or in other words, the shaders themselves do not have ultra fine control

langolierz, 2019-12-11:
No the shaders can take finer resolution, it’s just the the main loop is
not running fast enough to process more resolution without Lagging, or
something needs to be optimized first

On Wed 11. Dec 2019 at 23:44, ParticlesIntoWaves <notifications@github.com>
wrote:

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

langolierz, 2020-03-12:
i refactored the midi cc logic - it should be faster and smoother now than before - can reopen if still needed after testing new version, pending release

miroslawgwiazda, 2020-06-20:
I'm interested in the implementation of CV via midi in relation to clip/image changes, are you able to trigger changes synchronized to a beat? A simple example would be: one image triggered by a kick drum and another by a snare... Are load times fast enough for such an application? Any information would be much appreciated

langolierz, 2020-06-20:
👋 @miroslawgwiazda

this is a good question.  just to clarify you want to trigger something on a midi input ? or a cv / gpio pin input ?

if using midi , then you could map your trigger event to a midi note on , and this can be mapped to trigger changing the sample etc. if you are trying to trigger from a modular directly, probably best wou;d be a small transistor circuit to a gpio pin on the pi. then would need to add some code to listen to change on this pin in recur and map to an action. i can help if you want to go down this route.. (another way is using the existing cv extension circuit and writing a small action function that changes the clip when a cv threshold is reached - although this depends on the length of the 'trigger' )

> Are load times fast enough for such an application?

this depends a bit, basically the 'switching' is fast , but only when the next player is already loaded, which takes a second or two. so triggering on every kick might be too fast , but on every bar probably will be ok. in the main demo video there is a part where i am triggering video changes using a midi sequencer per bar like this

miroslawgwiazda, 2020-06-20:
I apologize this is my first foray into Raspberry Pi so elements of the platform are somewhat new to me. I was unaware of the GPIO option, would I need something to interface this with my Eurorack, a patch bay for example? Additionally, could this interpret other forms of CV with the end result being able to navigate through a single video by way of a modulation source?

Closed 2020-03-12.

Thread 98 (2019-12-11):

Banks of 8 instead of 10

ParticlesIntoWaves, 2019-12-11:
Ok I may be the only person to really care about this, but many if not all MIDI controllers have their pads and buttons arranged in banks 8 or 16. With recur being banks of 10, it’s not very elegant to map my MIDI controller. With a 16-pad controller, it would be ideal to map a bank of 8 videos and 8 shaders to the pads for activation and switching.

I know this somewhat “breaks” the arrangement of the keypad mapping, but I’m all for reassigning those two extra keys to perform other functions! ;-)

langolierz, 2019-12-11:
it sounds like mostly a mapping problem to me no ? i mean there is nothing stopping you only using 8 slots and remapping the other keys to hotkeys or something else you might prefer (i guess technically the display would have a couple lines of real-estate you werent using , but still)

and yeah in general i will be thinking about how to make the mappings more accessible.

ParticlesIntoWaves, 2019-12-11:
I guess you’re right, I don’t have to use 10 slots LOL.

Closed 2020-03-12.

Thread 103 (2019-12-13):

MIDI Enhancement: APC Key 25 support (LED feedback)

doctea, 2019-12-13:
I'm working on this over in my branch at https://github.com/doctea/r_e_c_u_r/tree/feature_midi_apckey25_feedback.  I've got a proof of concept working, with the 3 shader layers being controlled and represented with feedback with lit LEDs.

If anyone's got any ideas on what features they'd like to see mapped or want to beta test it as I go along, please post here or let me know!

doctea, 2019-12-19:
This has now turned into this branch https://github.com/doctea/r_e_c_u_r/tree/feature_midi_feedback_plugin which also now has:

  - Experimental 'plugin' architecture for adding functionality
  - MIDI feedback implemented as a type of plugin so should be fairly easy to add new controller types
  - "Shader Quick Preset Plugin" that can store/recall up to 10 shader presets (layers active, slots selected, parameter values, feedback state) triggerable via MIDI with LED feedback on APC Key 25
  - 'Sequence' plugin example that handles running sequences of parameter updates or other actions (automate parameters etc, run any python code..) with example of LED feedback on APC Key 25

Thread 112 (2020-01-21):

Building outside of Pi / Development Docs

averagehat, 2020-01-21:
It would be great to be able to build this project, and/or https://github.com/langolierz/c_o_n_j_u_r/ and/or https://github.com/langolierz/ofxVideoArtTools/ outside of the ARM architecture.

The big problem, at least with conjur/the ofx addon, seems to be the OMX dependency.

Being able to build in an emulator, or VM, or docker, or something would be helpful for development times. Has anybody have any ideas or experience trying?

Also, I can use some information for 'development' docs; so let me know what you've found useful for developing on the Pi 3 itself; particularly compile times, maybe you've installed libclang for editor support, I don't know.

langolierz, 2020-01-22:
This is a good one , actually a main motivator of abstracting out to
ofxVideoArtTools was to make the backend more cross platform ,
ofxVideoArtTools can switch between pi specific packages (for optimized
performance etc ) and ones that should work on a Mac etc.

I’m not sure how well it’s working like that right now but that was the
idea atleast , maybe I can try get this working / show an example or two ..

On Tue 21. Jan 2020 at 23:38, Mike Panciera <notifications@github.com>
wrote:

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

averagehat, 2020-01-22:
Cool. Right now c_o_n_j_u_r also has a direct dependency on omxplayer, I
think
I was not able to get omxplayer to build anywhere outside of a Pi

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

langolierz, 2020-01-22:
It shouldn’t , you can tell a recurVideoPlayrr what type to be , here :
https://github.com/langolierz/c_o_n_j_u_r/blob/master/src/ofApp.cpp#L25

, I think when the backend is set to ofPlayer it uses the default
openframeworks video player ,
Although maybe you then need to remove ofxOmxplayer from the addon.make also

On Wed 22. Jan 2020 at 15:26, Mike Panciera <notifications@github.com>
wrote:

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

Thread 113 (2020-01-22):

3D Rendering

averagehat, 2020-01-22:
I've marked what I'm actually working on with an open (or checkd, when I finish) checkbox
 - [ ] display a 3d scene
 - [ ] load 3d objects
    - [ ] STL files
    -   load other formats
- [ ] use a JSON config file to define groups vertex shaders, [maybe geometry shaders?] and 3d files, i.e. `{ 'threeDFile' : cube.stl, 'fragmentShader' : foo.frag, 'vertexShader' : bar.frag, 'postProcessingShader' : baz.frag}` (post-processing shaders don't seem necessary since they can be piped to a 1-input shader)

 - Add 3d object/vertex choices to the UI so other people can actually use them

 - [ ] Alter 3D scenes
   - [ ] add vertex-specific uniforms (these would be added to the MIDI mapping in such a way that a CC can be mapped to a vertex and shader uniform
   - [ ] via vertex 'deformation'
   - [ ] via rotation
   - via x/y/z scaling -- would have to be in the C++ code I think
   - via zoom/view shift -- done in OF, probably by moving the camera
   -  via speed/slow/reverse an animation; note that another way to do animation would be to sequence the MIDI CC and/or maybe @doctea 's sequencing plugin could do that?
    - keep the scene, change the 3d object/vertex shader/fragment shader

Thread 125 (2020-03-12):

redesign frame-sampling (detour)

langolierz, 2020-03-12:
the current detour implementation is hacky and confusing and not really used and partially redundant due to shader layer features..

it needs a redesign, making it simpler...

also can consider other playback modes like pingpong

doctea, 2020-03-12:
would also be good to be able to record multiple detour clip and switch/mix between them, persist between sessions etc :)

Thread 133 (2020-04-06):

Trouble with LPD8

MiddleJanuary, 2020-04-06:
Hello!

Big fan of the project! I have my r_e_c_u_r built, it does a lot of cool things!

I have an LPD8 connected to it and mapped out some midi functions.

CC #0 does not seem to work well with the LPD8.

I mapped the top 4 control knobs on the LPD8 as cc#0, cc#1, cc#2 and cc#3.

CC #1-3 work perfectly fine, it's cc#0 where I am having trouble.

When I turn the knob nothing happens. Does anyone else have this problem?

It works in the demo videos, not sure if I'm missing a line of code somewhere..

Or maybe I have a busted LPD8. Still running version 2.0.2, any info would help.

Cheers!

langolierz, 2020-04-06:
hii ! glad you are enjoying the project !

ahh.okay - the lpd8 is the same controller that i use to have (i broke the
usb-port off, still it sits in a pile waiting to be fixed..) , but yes i
guess it was working for me back then. 2 things i can think of that might
narrow the problem:

1 - what if you try mapping the top 4 control knobs to cc#3, cc#2, cc#1,
cc#0 ? if it was a problem with your controller i would expect now that
cc#3 would not work while the others do (same knob) , if not then its most
likely a problem with recur.

2 - maybe there is an off-by-one error where the code is reading cc#1 as
input 0 and cc#2 as input 1 and cc#3 as input 3 ? and this is why the first
knob does nothing ? to test this you could try mapping the top 4 controls
to cc#1, cc#2 and cc#3, cc#4 ?

if after trying both these things and problem is the same, could be a bug
in the code, we can try figure out.
lemme know how it goes !

On Mon, Apr 6, 2020 at 6:41 AM MiddleJanuary <notifications@github.com>
wrote:

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

MiddleJanuary, 2020-04-07:
Wow! Awesome trouble shooting!

Map 1: cc#3, cc#2, cc#1, cc#0
The first three knobs turn parameters 3, 2 and 1.
Nothing happens when I turn the 4th knob.

Map 2: cc#1, cc#2 and cc#3, cc#4
The first three knobs turn parameters 1,2 and 3.
The 4th knob does nothing, parameter 0 doesn't move at all.

This is fun! Very cool project!

Cheers!

MiddleJanuary, 2020-04-07:
Oh side note! Assigning cc#0 to a pad, then pressing the cc function on the LPD8 and hitting the pad, r_e_c_u_r does recognize the midi information and moves parameter 0 according to the velocity the pad was struck. Softer for lower numbers, harder for higher.

If it is a bug in the system, for some reason it only happens with the potentiometer value and not the pad.

Hope this helps!

Cheers!

langolierz, 2020-04-07:
That is very helpful , thanks. Well the good news your controller doesn’t
seem to be physically broken. But yeap it seems that the cc0 command is not
being interpreted correctly.

Others have told me there is problems with using cc0 because this usually
means LSB for a program change -
http://www.tweakheadz.com/midi_controllers.htm

Still I would like to know what exactly is being sent when you turn a knob
mapped to cc0 and how it is different to a pad mapped to cc0 !

I will take a look in the lpd8 mapping software and let you know what I find

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

MiddleJanuary, 2020-04-08:
I keep on thinking about a simple midi controller interface..

A lot of midi controllers have 8 or 16 pads, I've been thinking about a setup that would remove the need to include the 10 key pad.

Woke up early this morning and had to type out this 4 x4 setup..

   Normal setup                                                         Function Key enabled
   _________    _________    _________    _________	   _________    _________    _________    _________
   |             |   |             |   | select |   |              |         |            |    |             |   |slctshdr|   |             |
   |     <      |   |     >     |   |     ▇    |   |  dsply   |	   |      [     |   |      ]      |   |     ▇     |   |    —>   |
   |________|   |________|   |________|   |_________|	   |________|   |________|   |________|    |________|
   _________     _________    _________    _________	   _________    _________    _________    _________
   |             |   |      ◯     |   |             |   |             |	   |             |   |             |   |            |    |             |
   |     fn     |   |    rec    |   |      0     |   |      1     |	   |     fn     |   |    rec   |   |   clr [   |   |    clr ]   |
   |________|   |_________|   |________|   |________|	   |________|   |________|   |________|   |________|
   _________    _________    _________    _________	   _________    _________    _________    _________
   |             |   |             |   |             |   |             |	   |             |   |             |   |             |   |             |
   |      2     |   |     3      |   |     4     |   |      5     |	   |prv bnk|   |nxt bnk |   | clr bnk |  | mirror  |
   |________|   |________|   |________|   |________|	   |________|   |________|   |________|    |________|
   _________    _________    _________    _________	   _________     _________    _________    _________
   |             |   |             |   |             |   |             |	   |             |    |             |   |             |   |              |
   |     6      |   |      7     |   |     8     |   |      9     |	   | shader |   | frames |  |feedbck|  |shutdwn|
   |________|   |________|   |________|   |________|	   |________|    |________|   |________|   |_________|

I also have an idea for a midi map where the pad are in a 2 x 8 setup, like the Arturia Beatstep.

     Normal Setup
     _________   _________   _________   ________    ________    ________    ________   ________
     |            |   |            |   | select |   |           |   |            |   |           |   |           |   |           |
     |     <     |   |     >    |   |     ▇    |   |     0    |   |     1     |   |    2     |   |    3     |   |    4     |
     |________|   |_______|   |________|   |_______|   |_______|   |_______|   |_______|   |_______|
     _________    ________    ________    ________    ________    ________   ________    ________
     |             |   |    ◯    |   |           |    |           |   |           |   |           |   |           |   |            |
     |     fn     |   |   rec   |   | dsply |   |     5     |  |    6     |   |    7     |   |    8     |   |     9    |
     |________|   |_______|   |_______|   |________|  |_______|   |_______|   |_______|   |_______|

     Function Key Enabled
     ________    ________    ________    _______	_________    _________    _________    ________
     |           |   |           |    |           |   |           |	|             |   |            |   |              |   |            |
     |     [     |   |     ]     |   |    +     |   |  —>   |	|prv bnk|   |nxt bnk|   | clr bnk |   | mirror |
     |_______|   |_______|   |_______|   |_______|	|________|   |________|   |________|   |________|
     ________    ________    _______     ________	 ________     _________    ________     _________
     |           |   |           |    |          |   |            |	|             |   |             |   |             |   |             |
     |    fn    |   |   rec   |   |  clr [  |   |   clr ]  |    |shader |   |frames |   |feedbck|  |shutdwn|
     |_______|   |_______|   |_______|   |_______|	|________|   |________|   |________|   |________|
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
MiddleJanuary, 2020-04-08:
That's a cool setup!

Good to know that the newest release has cc values for note_on functions.

Didn't realize that recur does not support 2 midi controllers at once, that makes sense now.
Ruins my plans on buying a second LPD8 tho.. Damn that would have been a compact setup!
Came up with a list of midi controllers below or around $100, if any one is interested.

Akia LPD8

Akia MPD218

Akia MPK Mini MkII

Arturia Beatstep

Behringer CMD DC-1 (out of stock, still on eBay)

Behringer X-Touch Mini Ultra-compact Universal USB Controller‎

Korg padKONTROL

Korg nanoKONTROL2

Korg nanoPad 2

Native Instruments Maschine Mikro MKII MIDI Controller

Nektar Impact LX25+ 25-key Keyboard Controller

Samson Conspiracy MIDI controller

I'm sure there are others but those are just some personal favorites.
Also found a really cool DIY build on Adafruit, the Mini UNTZtrument: 3D Printed MIDI Controller.
Think I might build one of these, but add 8 more potentiometers.

Going back to the original problem, editing the midi map seems like the only solution.
Since I have to update to version 2.1.0, this would be a good time for that.

I am also still curious to why cc#0 doesn't work and am absolutely willing to run some commands on the pi if you can figure out what is happening. I was reading through the Facebook group and it looks like a handful of people are having trouble with cc#0, so if I can be of any help let me know.

Cheers!

MiddleJanuary, 2020-04-09:
I can't stop thinking about this..

16 pads, 16 knobs, an xy pad..   and audio input..

I'm thinking about making a pcb for an easy, inexpensive diy midi controller build.
I will definitely share the gerber files here once I'm done.

Looking for a simple xy pad solution, I realized v2.1.0 uses the touch screen.
Could be a possibility to assign a button to switch between modes, the settings menu and xy pad..

I also saw this software for $5 dollars!.. TouchOSC by Hexler Limited.
Could use a smart phone as an xy pad, or even create a whole 16pads/16knobs/xypad setup..

I know guergana is working on the r_e_m_o_t_e project. Maybe this could work there..
And I know doctea is working on "Sound reactivity [experimental]" I'll have to dig into those notes.

Again, I am also still curious to why cc#0 doesn't work and am absolutely willing to run some commands on the pi if you can figure out what is happening. If I can be of any help let me know!

I LOVE THIS PROJECT!!

langolierz, 2020-04-10:
im really glad you are excited about it - that was one of my main goals
when starting , to empower people to be part of creating the art-making
tools they want to use.

i also have been day-dreaming about making a little custom controller for
recur (although much smaller than what it sound like you have in mind) ,
the main thing stopping me is that the korg-nano does do almost every ting
i need now anyway , so hard to justify too much time into this but... yes
please share anything you come up with

re the xy-pad ; i looked into this i alil. it seems like you can get some
replacement touch pads for laptops to interface with arduino (
https://www.instructables.com/id/Arduino-Laptop-Touchpad/) , which could be
a place to start. and you are right , a cellphone is also a good source of
xy-action. the latest version supports osc so you can use touchOsc with it
already (ibought the software few months ago - it is nice), and there can
def make an xy-pad. and also plan to add this to the remote extension.

for sound reactivity, there is someone in the group who has made a custom
midi control with soundreactivity. they used something like  this i think
https://www.sparkfun.com/products/13116 , or another option is to use a
usb-audio device  like what Tristan (doctea) was working on. i would like
to work on this feature soon too because i already have some usb-capture
cards that input video to recur , would be nice to also get sound on them
aswell.

finally - thanks a lot for being willing to hunt this cc0 problem. i will
write a small python file on my pi that prints out the incoming commands
and then send it to you to run on yours and we can try spot the difference

On Thu, Apr 9, 2020 at 11:01 PM MiddleJanuary <notifications@github.com>
wrote:

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

hamsterwoede, 2021-06-25:
I have been setting up my LPD8 with r_e_c_u_r today, and found out that for some reason it just doesn't send anything on cc0. At least as far as I can see, nothing arrives on OSX.  I have had it working in the past with a previous version. But I might have also updated the firmware in the meantime. As far as I know it is a problem with the LPD8, and not so much r_e_c_u_r. Annoying really.

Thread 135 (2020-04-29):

Switch for hdmi_force_hotplug in settings page?

ParticlesIntoWaves, 2020-04-29:
I know my situation is, once again, unique, but I am constantly having to pop out the SD card and switch hdmi_force_hotplug on and off. This is because I am using a VGA adapter and it needs power over HDMI before it can tell the Pi there's an HDMI connection to be had, so without hotplug enabled it will default to composite out despite being connected to HDMI.

It would save me a lot of time if I could switch this on and off in the settings.

langolierz, 2020-05-29:
@ParticlesIntoWaves noted - this is possible and not too difficult as there is already code switching the sd video settings etc. will include this on the next version

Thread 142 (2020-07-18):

Quantize sample start/end to MIDI clock

TubularCorpration, 2020-07-18:
I think a really useful feature would be the ability to receive MIDI clock and set the start and end time to a user definable grid when the corresponding key on the keypad (or equivalent MIDI message) is received.  It would make it a lot easier (possible) to match loop lengths to music.

It would probably be good to also add a clock reset command to make it easy to fix sync issues that could happen if, say, Recur needed to be reset in a live situation - send the MIDI message bound to clock reset on the downbeat of a bar from your clock source and you'd be back in proper sync.

The basic idea being that you could set an arbitrary number of quarter notes (or ticks) and any loop start r end commands would be quantized to the NEXT CYCLE of that length.  So for example, setting a quantize length of 4 quarter notes/96 ticks wouldn't mean that the loop start would be set 96 ticks from the moment the button was pressed (the way some step sequencers handle event quantization), but rather there would be an internal counter that would start when r_e_c_u_r received its first clock message, and could be reset to 0 by a MIDI start message or any message bound to clock reset in the midi map file, and would reset every N tics, where N was the quantize value set by the user, the way quantizing to a grid in most piano roll sequencers.

Also, it would be really useful to be able to use MIDI CC to set the start and end points to arbitrary locations in the current clip.  Nothing complex, just (number of frames/128)*CC value, so a CC value of 0 would be the first frame, 64 would be the halfway point, etc.

Those two features would make it possible to integrate r_e_c_u_r into live music performance a lot more than you already can, without adding much complexity at all.

Unless it's already possible to do some or all of this and it isn't in the documentation yet. I know it's possible to continuously adjust the start and end points in detour but that's all I could find. One of the reasons it would be great to be able to do this in sampler (even if it's not as seamless as Detour) is that you could quickly select musically meaningful ranges out of a large file, and also because sampler has audio playback so it would be useful for integrating the audio from video files into the music.

langolierz, 2020-07-21:
hii @TubularCorpration ! and thanks for the detailed description / idea - i agree this would be a super useful way to enhance the "performance" aspect of this instrument (which is something i think about often)

when i first implemented midi i did try to also read the midi clock. one problem i found then was the clock is pretty fast and the python thread reading this is not super optimised , so i found it was flooding the message queue a bit and dropping some actual messages. (thats not to say it cant be done , just that would need to rethink this part a bit / play around to get it working)

for the main sampler engine (playing back video files) the shortest loop possible is around 2 seconds , which amounts to a lot of midi ticks (~23 000) -> in my [experiments](https://youtu.be/FKKDr7pLpp0?t=789), since triggering video files works better with longer cycles like bars rather than notes, i found that using a midi sequencer to send a SWITCH (->) command every bar / every four bars was a better way to synchronise

still i agree with you that having this kind of clock control would be rad - it is noted, and will take a look when im working on a new version (not sure when that will be though)

finally, selecting the start / end subloop points with midi-cc is possible (and pretty trivial to implement) ; the only problem is that setting a new loop point triggers a video reload (actually only a new _start_ point needs this) , so it would be better with some kind of _scroll_ then _accept_ interface (like a push encoder style) otherwise it will be constantly reloading a video on every value as you scroll over the timings with cc - ya know ?

TubularCorpration, 2020-07-21:
That makes a lot of sense, and as I use it more the MIDI clock idea seems less useful anyway.

For my use case, the CC to subloop points retriggering the sample wouldn't actually be an issue, but I definitely see how that would make it less useful if you were using the CC to scroll through timings.  What I actually had in mind was retriggering the video at different starting points from a step sequencer, essentially being able to do a crude version of sample slicing with a single video file.  I can get a bit of the way there by enabling random start in the setup menu but not being repeatable makes it only so useful, and also I've noticed that the random start points get less random as you retrigger a video more rapidly (below around 4 seconds it still randomizes but seems to only randomize between two or three specific points in the video; below about 2 seconds between retriggers it doesn't randomize at all).

If sending a single CC value to set the start point of the subloop also retriggered the current video that would actually make it work BETTER for what I had in mind than how I thought it would work (send a CC value to set the new start point and then a SWITCH command to manually retrigger). Obviously it would still be limited by the python performance you mentioned, but it would still be really useful to be able to do this in my opinion.

Hopefully that makes sense.  The simplest version is I'd like to be able to retrigger the current video at repeatable different start points from a step sequencer, and the behavior you described would actually be perfect for this even though it wouldn't work well for manually scrolling through start points. If it's easy for you to implement (or if you can point me in the right direction for doing it myself, with the caveat that I've got minimal coding experience and none in Python) it would be very appreciated!

doctea, 2020-07-21:
Great idea, was intrigued how to pull it off so had a quick look, this is my best take but I'm not overly familiar with the video stuff so please correct me if I'm wrong Tim:

Add a method to actions.py, called like "seek_to_position" that takes a 'position' value 0-1.  This method would check the current loop length from VideoPlayer and change the seek position as appropriate (position * length), similar to the seek_forward_on_player and seek_back_on_player methods.  You should then be able to bind 'seek_to_position' to a MIDI CC to control the playhead like a jog wheel?

Some of the features in the dev branch to allow more advanced MIDI mappings would make it possible to have specific timestamps  (not limited to MIDI 7bit resolution) set as macros that could be triggered by noteon/offs too.  I'll try and have a play with this when I get chance and see how it works.

Presuming that my assumption about how the video seeking works is in the right area of course? :)

TubularCorpration, 2020-07-22:
That sounds like it would do everything I'm after and more if it works.

doctea, 2020-07-23:
Oops didn't realise I'd committed it to your branch Tim, I meant to run it past you first, I usually got told I didn't have permissions when I tried to push -- thanks for giving me access!  Hope what I've pushed looks OK?

I've added the function I suggested above to the master branch, and to the dev branch too with some fixes to the ManipulatePlugin to make it easier to use random etc.

If I map a knob to /seek_to_location_on_player/ and turn it then the indicated play position moves and the video starts (after a bit of a delay that I presume is the video player seeking to position?).

On the dev version I've added examples to the json_objects/midi_action_mapping_APC Key 25.json file (right at the bottom) demonstrating how to map buttons to jump to 0, 25%, 50% and to a random position.

If you want to give it a try then you'll need to update to the latest dev image from and then hopefully 'UPDATE CODE' will work, but let me know how you get on @TubularCorpration !
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
doctea, 2020-08-08:
Ah, that's a shame that you can't get the dev version working :/.  Whereabouts does it hang on boot?

Regards the 14-bit msb/lsb thingy, I think the ManipulatePlugin binding as I wrote it above acts how you describe, although I'm not sure if the output is actually 14 bit resolution -- what its doing is:

For the broad control: `"set_variable_playheadmsb&&f:pc.actions.call_method_name('seek_to_location_on_player',((x*10) + playheadlsb)/11 ):|"`

- sets variable 'playheadmsb' to input value
- multiply value ('x' is the input value) by 10 and add the 'playheadlsb' value
- divide by 11 (10+1) to scale back to 0-1
- calls seek_to_location_on_player

(and the fine control does the same, but sets playheadlsb and uses the previously stored playheadmsb)

TubularCorpration, 2020-08-08:
I'll have to load it again to check exactly which service it's hanging on.  I didn't write it down because I figured I'd remember and of course I didn't.

That sounds like it should do what I was describing.

Anyway, for now I'm going to stick with the main version since I've already got it working with my keypad the way I want it to, but at some point I'll see if I can get the dev version working on another SD card with a keymap for the little 19 key numpad I've got, so I can at least try it out.

For now, being able to seek instantly with 32nd note resolution since I switched backends and codecs has changed everything, and that alone is going to give me a lot to work with.  Controlling the seek location with pitch bend would be a great option but even that is less important now.

doctea, 2020-08-25:
Hey @TubularCorpration, hope its still working OK for you? :)

> I did find this good, concise overview of pitch bend (and 14 bit MIDI messages in general) just now, might be of interest.

Did you mean to post a link here? :)

TubularCorpration, 2020-08-25:
Weird, I definitely pasted the URL in there, I'll try to track it down.

Still working great, but I've had a bunch of stuff to deal with plus the guy I've been livestreaming with is on vacation and we've been having a heat wave, so I've been mostly messing with Composers Desktop Project on the laptop and not doing anything that I need to turn on any hardware or the desktop for, just to avoid heat.

TubularCorpration, 2020-09-07:
Obviously I wasn't able to track it down again, I sort of lost track of this thread after I moved over to scanlines.xyz.

Midi CC to start point has been working VERY well for me, barring the occasional MIDI overflow if I try to send too much data (and quickly unplugging and replugging the USB cable from my sequenced fixes that 99% of the time). I'm going to try moving to using notes mapped to percentage soon so that I can take advantage of MIDI delay and arpeggiators, but haven't had a chance to set it up yet. Also, the response is fast enough with h264 encoded files that finger drumming should actually be possible.

langolierz, 2020-09-08:
btw if you havnt found it already there is a channel in the scanlines chat
where we can discuss this project too
https://chat.scanlines.xyz/channel/r_e_c_u_r

On Tue, Sep 8, 2020 at 12:34 AM TubularCorpration <notifications@github.com>
wrote:

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

TubularCorpration, 2020-09-08:
Thanks, I hadn't really looked at chat yet and hadn't seen it, that would be more convenient for sure.  I'll close this.

Closed 2020-09-08.

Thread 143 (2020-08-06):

MIDI CC to rate?

TubularCorpration, 2020-08-06:
I've been poking around in the video player code a bit and it looks like it wouldn't be that tough to implement CC control of playback rate, but I'm not sure what the valid range of speed values are. I think I could probably work out how to scale CC data to a valid range and write an action that would read the current playback location, set the rate to the scaled CC value, and then retrigger the clip from the current playback location that was read earlier (from what I can tell the current increase/decrease speed functions have to retrigger the current clip to make the speed change take effect, so I'm assuming if I wanted to change the speed on the fly without changing the current playback location the function would need to retrigger it at the current location after setting the new rate).  Does this sound correct?

I'm basically looking for a way to set the speed to a specific value via MIDI in the same way I've been setting the playback position, so the sequencer I'm using to control playback position can use a different CC to control speed. Not expecting smooth changes, just looking to fire off single CC values.

Also when I was in there I noticed a typo in actions.py:

    def decrease_speed(self):
        print("increasing speed !")

langolierz, 2020-08-07:
Re the video playback speed...

I thought it would be possible to implement this too. Actually I spent a
very long time trying to get this working (hence all the code /comments
Around the place for this haha) but it never really worked that well ...
only sometimes for some videos etc. you can try uncomment those parts and
play around but yah it can be a bit frustrating. Also this is partly why I
started working on detour the frame sampler... but yeah I know it’s not
quite the same

On Fri 7. Aug 2020 at 01:25, TubularCorpration <notifications@github.com>
wrote:

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

TubularCorpration, 2020-08-07:
Probably not worth the effort then.  Speaking of intermittent, using low resolution CC LFOs was working great two days ago, and then the next day with the same settings and clip it didn't work reliably at all, even the slowest setting was more than it could handle, so who knows.  I'm getting more than enough variation just with CC to position on mutiple tracks, once I have a few long chains built I can use one track to change clips and a couple of other tracks to change playback position and end up with a lot of semi-generative variety, and then reserve LFOs for controlling shaders when I start using those.

Detour actually seems really promising, I'm just trying to focus on one area at a time as I figure out how I want to fit it in to my workflow.

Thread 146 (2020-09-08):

new control scheme (for default?) / nanokontrol

langolierz, 2020-09-08:
it has been suggested to me from @ParticlesIntoWaves that this would be an ideal control scheme for using recur with nanokontroller (and not needing to rely on the keypad which can be a bit hacky)

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

> An alternative idea for the 1–8 buttons
-Top row is video slots
-Second row is video banks
-FN+second row buttons is shader banks
I realize r_e_c_u_r can do more videos and banks than this but 8x8 is the most elegant for NK2... and is still plenty of videos

on the whole i dont think it would take much to implement this.

i have a few open questions like whether we should create 'breaking changes' with the default layout or add a setting option to choose from different layout schemes...

besides that i think everything thing else will be possible by editing the mapping json

Licoricious, 2020-10-13:
I think a setting option to choose between this and the current control scheme would be excellent. I definitely think this layout would work better for controlling _recur_, but I also enjoy having some assignments free for me to control other gear simultaneously. The default scheme should probably remain the same, at least for now ("WE DO NOT BREAK USERSPACE"-LT). Down the road, I think it wouldn't be too hard to implement a MIDI learn mode and the ability to save various control schemes--but that's getting ahead of ourselves at the moment.

doctea, 2021-03-12:
I might be biased ;-) but I'd like to see this done using the controller-specific mapping stuff I implemented for the APCKEY25.  That way you could have this be the default control layout for the Nanocontrol, but keep the 'old' mapping for other controllers, and expand in future with layouts that make sense for other controllers too.

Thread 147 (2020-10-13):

LOOP_TYPE parallel sampler issues

Licoricious, 2020-10-13:
I was playing around in parallel mode tonight, and noticed some irregularities in the loading behavior.

1. When playing a video in the NOW player, with the NEXT player selected (cyan bar at top) and next.player.toggle_show() set to false:

When you load a video into the NEXT player,  next.player.toggle_show() is set to TRUE. This causes switch_to_next_player to toggle_show() for both the NOW and NEXT players to FALSE--hence dropping video feed.

2. When playing a video in the NEXT player, with the NOW player selected (yellow bar at top) and now.player.toggle_show() set to false:

When you load a video into the NOW player, now.player.toggle_show() is set to TRUE. This causes playback to jump to the NOW player, even if that was unintended.

It's pretty clear these things are two manifestations of the same bug.
I have a guess as to the cause of these issues (line 136 in actions.py), but I wanted to make a post, as I have no experience in
Python or with Github in the past, so it may take a bit for me to fix this on my own.

My apologies if this behavior is working as intended or I'm misunderstanding something.

langolierz, 2020-10-13:
thanks for the heads up @Licoricious !

that does sound strange, and the code on line 136 looks a bit off too. most likely it is a bug (or some weird thing i was trying and forgot to fix)

i would have to try it myself to check, but meanwhile if you want to try edit the code yourself to do something that makes more sense i can help you get set up with that. maybe can then merge your changes into main if it is better.

Licoricious, 2020-10-14:
So commenting out that line fixes situation 1 above, albeit in a somewhat hacky way. It ends up switching channels simply by toggle_show()-ing the NOW player. This works since the NOW player appears above the NEXT player.

Situation 2 is a bit trickier. The root of the problem seems to be that reloading the player sets toggle_show() to TRUE, when you really want to leave it in whatever state it was before. I tried added another line to turn it back off, but due to loading time delay the behavior is highly inconsistent. I'm gonna keep messing around and see if I can find a simple solution to this.

langolierz, 2020-10-14:
thanks so much for looking into it (and happy you are figuring it out !)
when im on recur next i will also take a look and let you know what i find

On Wed, Oct 14, 2020 at 9:49 PM Licoricious <notifications@github.com>
wrote:

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

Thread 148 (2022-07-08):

Menu changing skipping

mcartagenah, 2022-07-08:
Hi, I'm using the 2.1.0 beta image and after enabling some of the extra menus (shader mod, shader bank, frames) when changing menus with the dsply button it  doesn't cycle correctly and skips to the second to last menu, and if I try to move to the last one it automatically moves back, but if I cycle backwards using fn+dsply I can stay in almost every menu if I hold it for a second.

It's a weird behaviour and it's hard to explain it :(

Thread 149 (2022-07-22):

White background on LCD

bsom, 2022-07-22:
Any idea why on my freshly built r_e_c_u_r using the 2.1.2 image the background of the LCD is white instead of black?

octopus-arts, 2023-07-08:
Same here + the displayed output is upside down relative to the HDMI and composite outputs.

octovolt, 2023-10-28:
This might be a Waveshare firmware issue. My version of the LCD is a Waveshare 3.5inch RPi (B), which is giving me inverted colors. I'm still trying to figure out how to fix it, but I'm hopeful that this discussion will point me in the right direction: https://raspberrypi.stackexchange.com/questions/113522/3-5-inch-rpi-lcd-with-colors-problem

I was able to rotate the display in config.txt by changing this line:
```
dtoverlay=waveshare35a:rotate=270
```
to this:
```
dtoverlay=waveshare35a:rotate=90
```

cyberboy666, 2023-10-28:
thanks for this info !

i have heard a few reports from people about this inverted display

easiest thing to do i think would be to add an option in the settings that lets you invert the display in the python code.. shouldnt be hard to do and also as bonus maybe some people prefer the white background version in some context...

im not really releasing new versions of this project any more - but can try find time to figure out how to do this inverting since its a request i get every so often.

also while here could add a `flip display` settings option too - which would do it the same way you describe here with the dtoverlay

mrfugu, 2023-10-28:
Still ppl out here that would love to see rpi4, or 5 builds, thinking/assuming that the video and camera delay times could be greatly reduced…. But completely understand why one would want to avoid  going down the rabbit hole again with an old abandoned project, Cheers!!Mrfugu Sent from my iPhoneOn Oct 28, 2023, at 17:17, cyberboy666 ***@***.***> wrote:
thanks for this info !
i have heard a few reports from people about this inverted display
easiest thing to do i think would be to add an option in the settings that lets you invert the display in the python code.. shouldnt be hard to do and also as bonus maybe some people prefer the white background version in some context...
im not really releasing new versions of this project any more - but can try find time to figure out how to do this inverting since its a request i get every so often.
also while here could add a flip display settings option too - which would do it the same way you describe here with the dtoverlay

—Reply to this email directly, view it on GitHub, or unsubscribe.You are receiving this because you are subscribed to this thread.Message ID: ***@***.***>

jfre1, 2025-01-18:
The fix is using the different overlay and calibration.

When you use the script as statet in the waveshare display manual, it overwrites the config.txt, but also overwrites other things like cmdline.txt and xorg, fbcp:
https://www.waveshare.com/wiki/3.5inch_RPi_LCD_(B)

Here is the script code:
https://github.com/waveshareteam/LCD-show/blob/master/LCD35B-show-V2

I used this and changed things back after that, but it's maybe better, to just copy the overlays for 35-b-V2 from here:
https://github.com/waveshareteam/LCD-show/tree/master/boot

and put them in the boot folder on the pi.

Then you have two options:

### 1) a short and simple option (quick and dirty), but you can't use the dev mode anymore:

change in config config.txt

from
`## switch for enabling lcd screen (the next line is being used even if its commented out)`
`##no_waveshare_overlay`

or (depends if you are in dev mode or not)
`## switch for enabling lcd screen (the next line is being used even if its commented out)`
`dtoverlay=waveshare35a:rotate=270`

to
`## switch for enabling lcd screen (the next line is being used even if its commented out)`
`dtoverlay=waveshare35b-v2:speed=38000000,rotate=90`

The speed is to change the SPI speed, so you get more frames. Every display is different, so you can experiment, if you can go higher. For me, 38000000 was maxed out before the colors are glitching around.

### **2) the "advanced" option, to have all functionallity, but it's more time consuming:**

_(I use my display upside down to have the i_n_c_u_r controls above the screen, but if you want to have it below, you have to change the code to `rotate=90` instead of `rotate=270` )_

At first, you have to do the quick version too, but after that, there are some more things to do:

There are two scripts in the dotfiles, you have to change:
https://github.com/cyberboy666/r_e_c_u_r/blob/master/dotfiles/switch_display_to_hdmi.sh
from
`sudo sed -i "s/##no_waveshare_overlay/dtoverlay=waveshare35a:rotate=270/g" /boot/config.txt`
to
`sudo sed -i "s/dtoverlay=waveshare35b-v2:speed=38000000,rotate=270/##no_waveshare_overlay/g" /boot/config.txt`

Next, there is also the counterpart:
https://github.com/cyberboy666/r_e_c_u_r/blob/master/dotfiles/switch_display_to_lcd.sh

`sudo sed -i "s/##no_waveshare_overlay/dtoverlay=waveshare35a:rotate=270/g" /boot/config.txt`
to
sudo sed -i "s/##no_waveshare_overlay/dtoverlay=waveshare35b-v2:speed=38000000,rotate=270/g" /boot/config.txt

but we are not finished yet! In the actions.py:
https://github.com/cyberboy666/r_e_c_u_r/blob/master/actions.py

Find the "switch_display_to_hdmi" function. For me it's line 729, but i've editet some things and I'm on the 2.10 image, so it could be a other line for you. It should look like this:

`def switch_display_to_hdmi(self):
        with open('/boot/config.txt', 'r') as config:
            with open('/usr/share/X11/xorg.conf.d/99-fbturbo.conf') as framebuffer_conf:
                if 'dtoverlay=waveshare35a,rotate=270' in config.read() and 'dev/fb1' in framebuffer_conf.read():
                    self.run_script('switch_display_to_hdmi')
                else:
                    self.message_handler.set_message('INFO', 'failed to switch display')`

then change it to:

`def switch_display_to_hdmi(self):
        with open('/boot/config.txt', 'r') as config:
            with open('/usr/share/X11/xorg.conf.d/99-fbturbo.conf') as framebuffer_conf:
                if 'dtoverlay=waveshare35b-v2:speed=38000000,rotate=270' in config.read() and 'dev/fb1' in framebuffer_conf.read():
                    self.run_script('switch_display_to_hdmi')
                else:
                    self.message_handler.set_message('INFO', 'failed to switch display')`

I'm not sure if i forgot something, because i changed it like two months ago. I don't use the touchscreen, but for me it's like inverted. Maybe there is something to change in the calibration, but i don't use it anyway.

There is also an interesting project, that's getting more fps out of the waveshare screens (mostly for gaming), but i don't think it's know if it's possible to use this for r_e_c_u_r and is maybe hard to implement:
https://github.com/juj/fbcp-ili9341
https://www.youtube.com/watch?v=dqOLIHOjLq4

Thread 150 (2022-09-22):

emoji in sample title causes crashes

cyberboy666, 2022-09-22:

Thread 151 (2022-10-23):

Unlimited sample / shader slots

tandy-1000, 2022-10-23:
Is there a hard limit on the number of sample / shader slots?
I've made a custom mapping for the Launchpad Mini, adding mappings for 64 slots in total. I haven't been able to test this mapping properly yet.

Is there functionality in the code to support this?

cyberboy666, 2022-10-23:
thats a good question.

in the case of samples you can already have unlimited slots. they are broken out over 'banks' (each of 10 slots) that are displayed on the screen. but you can have as many as you like

if you had (for example) 7 banks full of 10 samples each it would be possible to write a mapping that triggered each slot with a press of your launch pad button

you would just need to write a small helper function in `actions.py` that takes the bank and slot number from the mapping - (something like this might do it although i havnt tested):

```python
def _load_this_slot_and_bank_into_next_player(self, slot, bank):
    if len(self.data.bank_data) <= bank:
        self.message_handler.set_message('INFO', "bank %s doesnt exist" % bank)
    else:
        self.data.bank_number = bank
        self._load_this_slot_into_next_player(slot)
```
and then all you need to do is write the specific functions that are set in the json mappings:
```python
def load_slot_0_bank_3_into_next_player(self):
    self._load_this_slot_and_bank_into_next_player(0,3)
...
```

the case for unlimited shaders is a little bit more tricky since they dont have _unlimited_ banks like samples do. shaders have 3 _layers_ (which interact with each other and are a bit more 'hardcoded' into the backend) - it would be possible to increase number of layers although requires more changes. the other option would be to increase the size of each layer - the only reason it is 10 is coz thats what can fit on the display... maybe a way to 'scroll down' the layer on the display would make sense in this case. or a quicker more hacky approach would be just to hard-code all the shaders into one big layer that you cant see or change. but can switch between with ur launchpad...

tandy-1000, 2022-10-24:
I see, thanks for the quick reply, seems like I'll have to explore this a bit more.
If python had meta-programming features like nim that would make the specific functions a lot easier ...
I understand now, the way I understood it was that shaders were "played" similarly to samples, that makes sense.
Thanks!

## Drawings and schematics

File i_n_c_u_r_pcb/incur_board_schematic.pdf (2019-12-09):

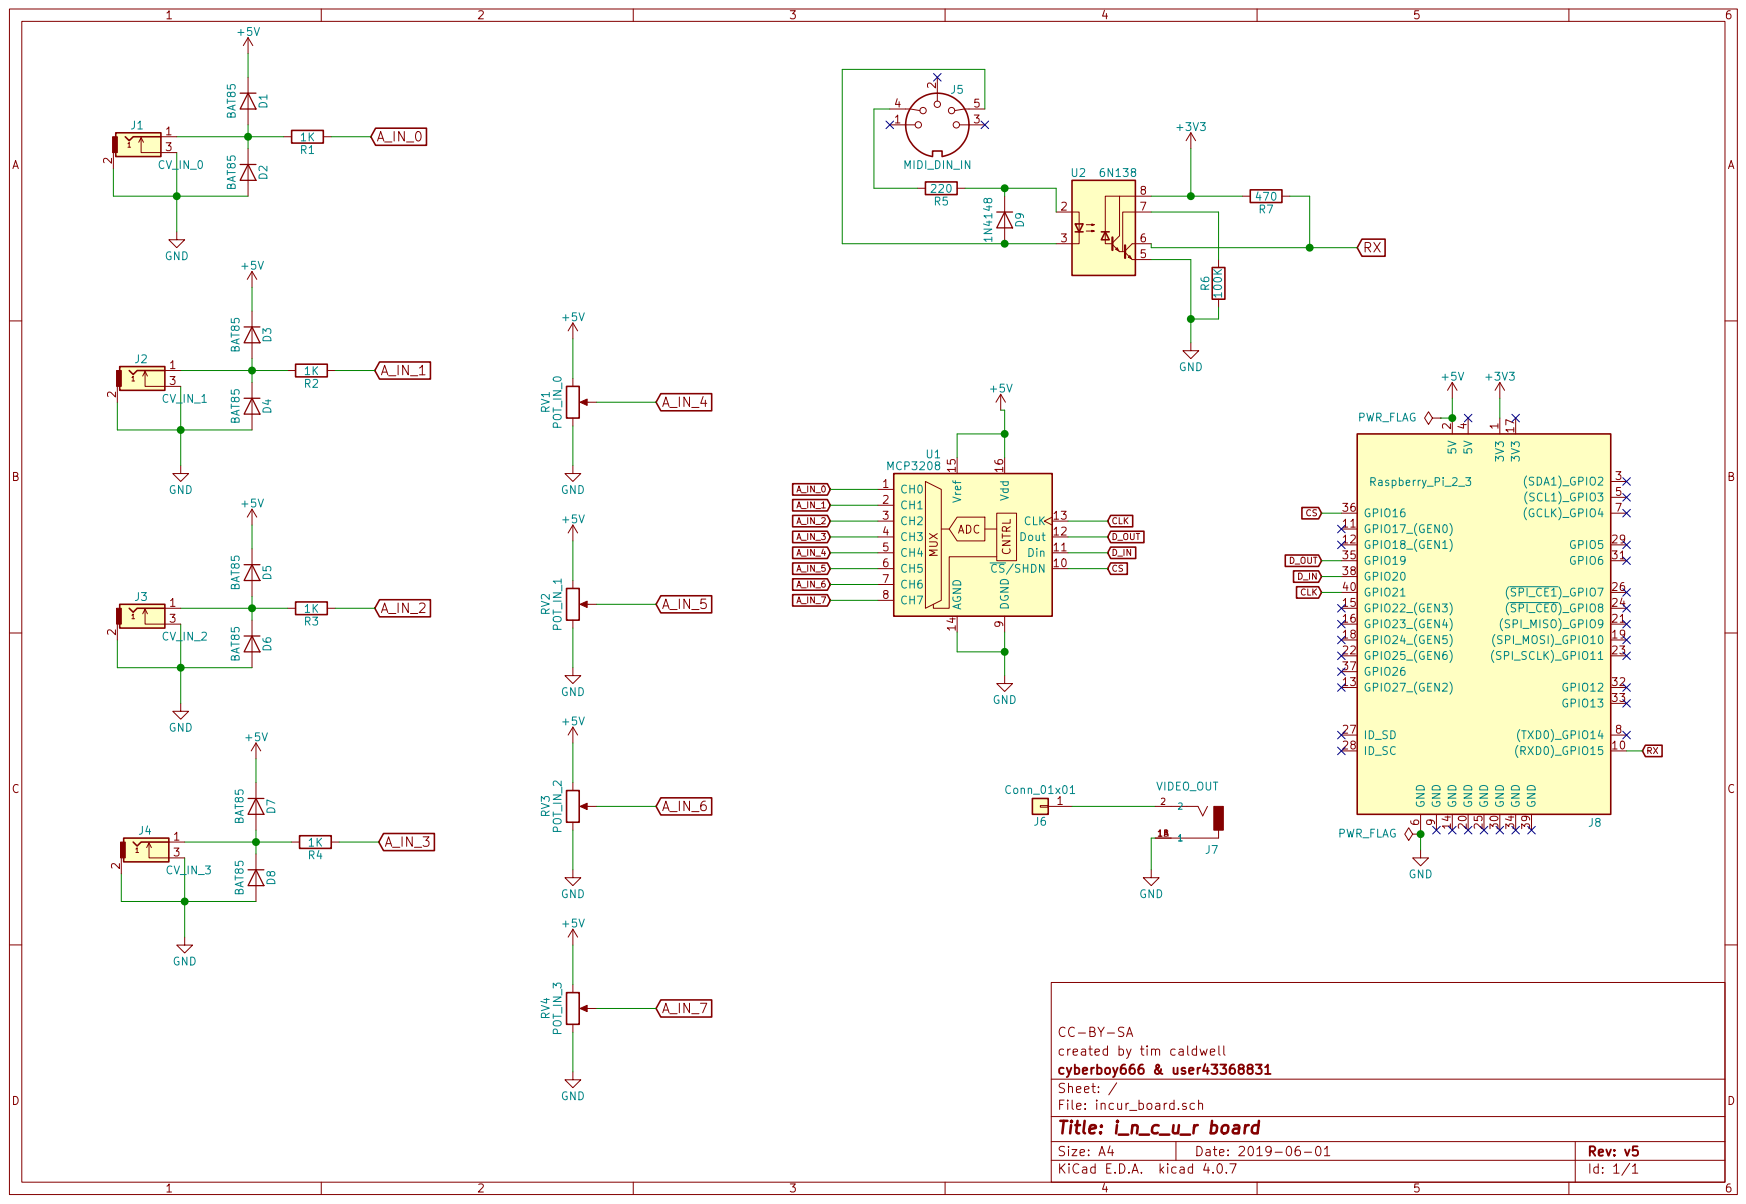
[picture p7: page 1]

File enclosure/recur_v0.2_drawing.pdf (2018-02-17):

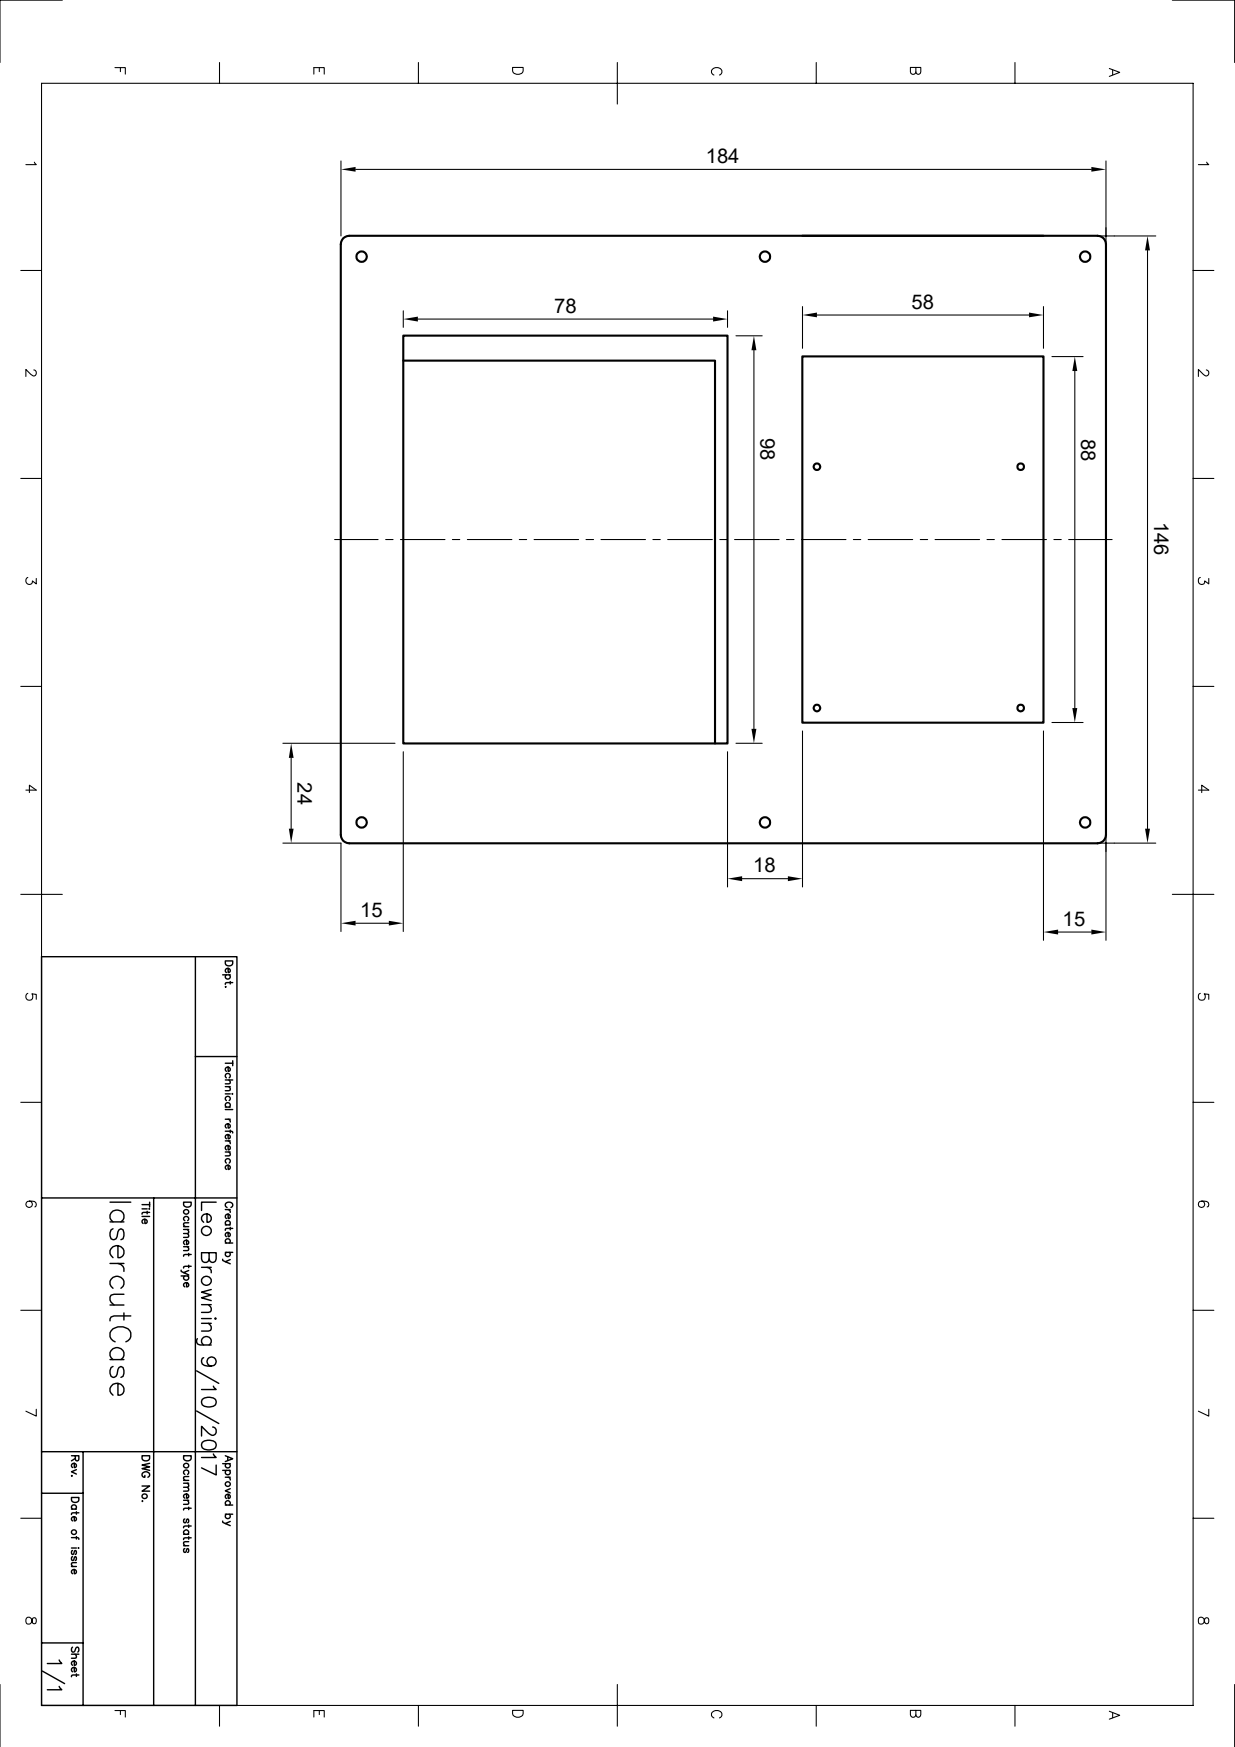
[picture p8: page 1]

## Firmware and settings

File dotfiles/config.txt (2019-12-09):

# For more options and information see
# http://www.raspberrypi.org/documentation/configuration/config-txt.md
# Some settings may impact device functionality. See link above for details

## gives more memory to the gpu for playing 1080 videos (might need to adjust this when using older pis with less memory)
gpu_mem_256=120
gpu_mem_512=200
gpu_mem_1024=448
gpu_mem=448
## enables the raspi camera
start_x=1
##fixes bug with playback freezing
audio_pwm_mode=0

# uncomment if you get no picture on HDMI for a default "safe" mode
#hdmi_safe=1

# uncomment this if your display has a black border of unused pixels visible
# and your display can output without overscan
#disable_overscan=1

# uncomment the following to adjust overscan. Use positive numbers if console
# goes off screen, and negative if there is too much border
#overscan_left=16
#overscan_right=16
#overscan_top=16
#overscan_bottom=16

# uncomment to force a console size. By default it will be display's size minus
# overscan.
#framebuffer_width=1280
#framebuffer_height=720

# uncomment if hdmi display is not detected and composite is being output
#hdmi_force_hotplug=1

# uncomment to force a specific HDMI mode (this will force VGA)
#hdmi_group=1
#hdmi_mode=1

# uncomment to force a HDMI mode rather than DVI. This can make audio work in
# DMT (computer monitor) modes
#hdmi_drive=2

# uncomment to increase signal to HDMI, if you have interference, blanking, or
# no display
#config_hdmi_boost=4

# uncomment for composite PAL
sdtv_mode=00
sdtv_aspect=1
#uncomment to overclock the arm. 700 MHz is the default.
#arm_freq=800

# Uncomment some or all of these to enable the optional hardware interfaces
dtparam=i2c_arm=on
#dtparam=i2s=on
dtparam=spi=on
enable_uart=1
# Uncomment this to enable the lirc-rpi module
#dtoverlay=lirc-rpi

#setup midi over serial
dtoverlay=pi3-miniuart-bt
dtoverlay=midi-uart0


## switch for enabling lcd screen (the next line is being used even if its commented out)
##no_waveshare_overlay

# Additional overlays and parameters are documented /boot/overlays/README

# Enable audio (loads snd_bcm2835)
dtparam=audio=on

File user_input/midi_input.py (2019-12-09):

import string
import datetime
import mido
import subprocess

class MidiInput(object):
    def __init__(self, root, message_handler, display, actions, data):
        self.root = root
        self.message_handler = message_handler
        self.display = display
        self.actions = actions
        self.data = data
        self.midi_mappings = data.midi_mappings
        self.midi_device = None
        self.midi_setting = None
        self.port_index = 0
        self.midi_delay = 40
        self.try_open_port()

    def try_open_port(self):
        #self.data.midi_status = 'disconnected'
        self.midi_setting = self.data.settings['user_input']['MIDI_INPUT']['value']
        self.port_index = self.data.midi_port_index
        #print('try open port : midi setting is {}'.format(midi_setting))
        if self.midi_setting == 'usb':
            self.actions.stop_serial_port_process()
            self.open_this_port_and_start_listening('20')
        elif self.midi_setting == 'serial':
            self.actions.create_serial_port_process()
            self.open_this_port_and_start_listening('serial')
        else:
            self.actions.stop_serial_port_process()     
            self.data.midi_status = 'disconnected'
        self.root.after(1000, self.try_open_port)

    def open_this_port_and_start_listening(self, port_phrase):
        midi_ports = mido.get_input_names()
        midi_device_on_port = [s for s in midi_ports if port_phrase in s]
        if midi_device_on_port:
            if self.data.midi_status == 'disconnected':
                subport_index = self.port_index % len(midi_device_on_port) 
                self.midi_device = mido.open_input(midi_device_on_port[subport_index])
                self.data.midi_status = 'connected'
                self.message_handler.set_message('INFO', 'connected to midi device {}'.format(self.midi_device.name))
                self.poll_midi_input()
        elif self.data.midi_status == 'connected':
            self.data.midi_status = 'disconnected'

    def poll_midi_input(self):
        i = 0
        cc_dict = dict()
        for message in self.midi_device.iter_pending():
            i = i + 1
            message_dict = message.dict()
            midi_channel = midi_setting = self.data.settings['user_input']['MIDI_CHANNEL']['value'] - 1

            if not message_dict.get('channel', None) == midi_channel:
                pass
            ## turning off noisey clock messages for now - may want to use them at some point
            elif message_dict['type'] == 'clock':
                pass
            ## trying to only let through step cc messages to increase response time
            elif message_dict['type'] == 'control_change':
                control_number = message_dict['control']
                print('control number is {} , cc_dict.keys is {}'.format(control_number, cc_dict.keys() ))
                if not control_number in cc_dict.keys():
                    cc_dict[control_number] = message_dict['value']
                    self.on_midi_message(message_dict)
                else:
                    step_size = 3
                    ignore_range = range(cc_dict[control_number] - step_size,cc_dict[control_number] + step_size)
                    #print('value is {} and ignore range is {}'.format(message_dict['value'], ignore_range ))
                    if not message_dict['value'] in ignore_range:
                        cc_dict[control_number] = message_dict['value']
                        #print(message_dict)
                        self.on_midi_message(message_dict)
                    #print(cc_dict)

            else:
                print(message_dict)       
                self.on_midi_message(message_dict)
        if i > 0:
            pass
            #print('the number processed {}'.format(i))
        if self.data.settings['user_input']['MIDI_INPUT']['value'] == self.midi_setting and self.data.midi_port_index == self.port_index:
            self.root.after(self.midi_delay, self.poll_midi_input)
        else:
            self.data.midi_status = 'disconnected'

    def on_midi_message(self, message_dict):
        if message_dict['type'] == 'note_on' and message_dict['velocity'] == 0:
            ## edge case where on note of zero alternative for off note.
            message_dict['type'] = 'note_off'
        mapped_message_name = message_dict['type']
        mapped_message_value = None
        if 'note' in message_dict:
            mapped_message_name = '{} {}'.format(mapped_message_name,message_dict['note'])
        if 'control' in message_dict:
            mapped_message_name = '{} {}'.format(mapped_message_name,message_dict['control'])
            mapped_message_value = message_dict['value']
        
        if mapped_message_name in self.midi_mappings.keys():
            self.run_action_for_mapped_message(mapped_message_name, mapped_message_value)
        else:
            print('{} is not in midi map'.format(mapped_message_name))

    def run_action_for_mapped_message(self, message_name, mapped_message_value):
        this_mapping = self.midi_mappings[message_name]
        if self.data.control_mode in this_mapping:
            mode = self.data.control_mode
        elif 'DEFAULT' in this_mapping:
            mode = 'DEFAULT'

        if self.data.function_on and len(this_mapping[mode]) > 1:
            method_name = this_mapping[mode][1]
            self.data.function_on = False
        else:
            method_name = this_mapping[mode][0]

        print('the action being called is {}'.format(method_name))
        if mapped_message_value is not None:
            norm_message_value = mapped_message_value/127 
            
        else:
            norm_message_value = None
        self.call_method_name(method_name, norm_message_value)
        ## only update screen if not continuous - seeing if cc can respond faster if not refreshing screen on every action
        if 'continuous' not in message_name:
            self.display.refresh_display()

    def call_method_name(self, method_name, argument=None):
        if argument is not None:
            getattr(self.actions, method_name)(argument)
        else:
            getattr(self.actions, method_name)()

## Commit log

2017-10-12 button press switches video
2017-10-12 adding reload on button press
2017-10-12 testing current position update
2017-10-12 added switching between browser and looper
2017-10-16 fixed current position
2017-10-16 started quit button
2017-10-16 finished exit button
2017-11-17 added scripts for switching screens and launching
2018-01-04 fixed getting duration issue
    [numpad_input.py]
2018-01-04 update display to show cropped video and fixed seek boundary error
    [numpad_input.py]
2018-01-04 fixing the display issues
    [numpad_input.py]
2018-01-28 added switching the screens to actions in the settings
2018-02-17 dimensional drawing for recur case
2018-02-18 tidy up video player logic so that switch button is stronger and loop should stop when error state is reached
2018-03-13 added dispay driver to repo
    [config-101-1024x600.txt, config-32.txt, config-35.txt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]
2018-03-13 switch screens scripts changed to point to the tracked drivers
2018-03-14 updated to correct font and added splash option to the driver cmdline.txt
2018-04-04 extended the time to prep a clip , reducing the issue with flickering change overs sometimes, focing audio out to local to avoid hdmi freezing issues (a known bug in omx player) added actions for har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
    [config-nomal.txt]
2018-04-06 increased gpu memory to handle 1080 files, included info message for files that cant be played and for when bank is full, allowed .mov and .avi files to be displayed
    [config-nomal.txt]
2018-04-19 adding the ability to record and display the capture device
2018-04-19 automap recording into sampler and displaying the capture info
2018-04-20 trying cc to change cameras color
    [config-nomal.txt]
2018-04-20 ensuring camera is connected before trying to capture
2018-04-20 updated the function key to switch off after use
2018-04-25 connecting up some of the new settings including switching video modes
2018-04-25 fixed menu scrollign bug and added some sampler settings
2018-04-26 experimental work with dif sampler playmodes
2018-04-30 improved the scripts to switch between dev mode
2018-04-30 persist and check video settings, removed lcd drivers from codebase
    [config-101-1024x600.txt, config-32.txt, config-35.txt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]
2018-04-30 fixed a bug , made sure camera preview is on top , reloads current player if layer gets to zero ...
2018-05-02 added new sampler modes incl random start and fixed length
2018-05-02 added gated key pressing option to action and function button
2018-05-03 tidying up the video player and driver
2018-05-03 improved error handling and logging
    [midi_input.py, numpad_input.py]
2018-05-03 added tap tempo input for fixed length mode
    [numpad_input.py]
2018-05-06 fixing some bugs found during tests for demo
    [midi_input.py]
2018-05-06 added stl of 3d print enclosure
    [baseplate.stl, topplate.stl]
2018-05-11 plugged a large memory leak, there still seems to be a small one - added a program reset as workaround for now
    [midi_input.py]
2018-05-16 added option to drop output modew to 720 for some hdmi devices...
2018-07-31 update pin info
2018-09-23 adding input selection for picapture and tidied up the camera code a lil
2018-09-24 fixed a few small bugs and only read analog inputs if there is a change
    [analog_input.py, midi_input.py]
2018-10-01 working on camera into of
2018-10-02 created seperate class for of_capture so they do not compete for access to camera etc
2018-10-03 switching between of camera and python camera input
2018-10-08 a bunch of small bugs and tasks and fixes
    [analog_input.py]
2018-10-13 fixing capture bugs and shader display problems
    [analog_input.py]
2018-10-15 improved capture switching and serial midi
2018-10-18 Seek Time Adjustment
    Added mapping and action to change the seek time using fn + </>.
    Parameter added to the sampler settings called SEEK_TIME_JUMP. This parameter sets how much the seek time is adjusted by each time fn + </> is pressed. SEEK_TIME_JUMP also stores the custom seek time.
2018-12-01 updated incur schmeatic and included gerbers for v1 of pcb
2018-12-19 improved the dev mode switching and some other things
2019-02-23 adding midi map, shader param setting, fixing midi bug
    [midi_input.py]
2019-02-23 fix bug in midi fix
    [midi_input.py]
2019-06-08 add config to dotfiles
    [config.txt]
2019-06-09 fixed refactor, added player reset
    [analog_input.py]
2019-06-29 usb camera recording and detour demo
2019-07-06 add board picture
2019-08-04 fixing small bugs and adding small features
    [config.txt]
2019-08-07 ignoring some settings and fixing video mode switch
2019-12-08 removing docs from repo - and put in wiki
    [baseplate.stl, topplate.stl]
2020-07-23 backport from dev the ability to seek to a percentage of currently playing video
